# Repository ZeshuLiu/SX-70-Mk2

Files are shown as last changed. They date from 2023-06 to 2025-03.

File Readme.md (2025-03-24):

# SX-70 Mk2

## 介绍
针对SX-70 Sonnar相机的现代化改造，在保留原本机身的自动功能的情况下，提供更直接的手动控制方式，能够更加自由地进行拍摄。**安装机身控制器后手动控制更加方便** \
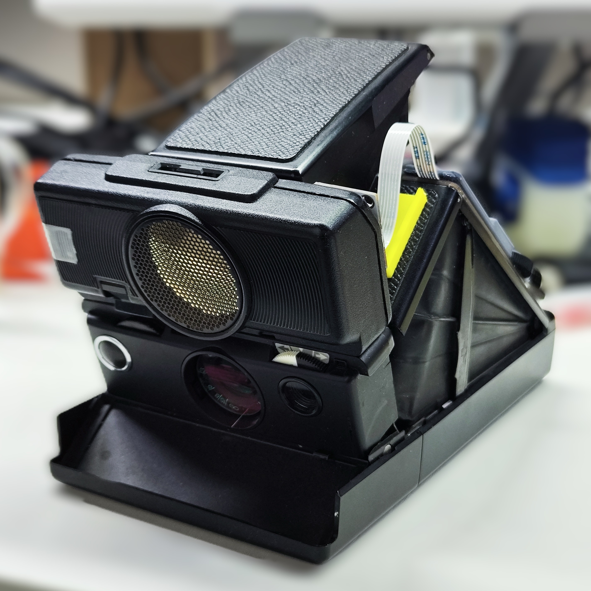
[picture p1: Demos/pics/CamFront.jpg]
相机正面 Front


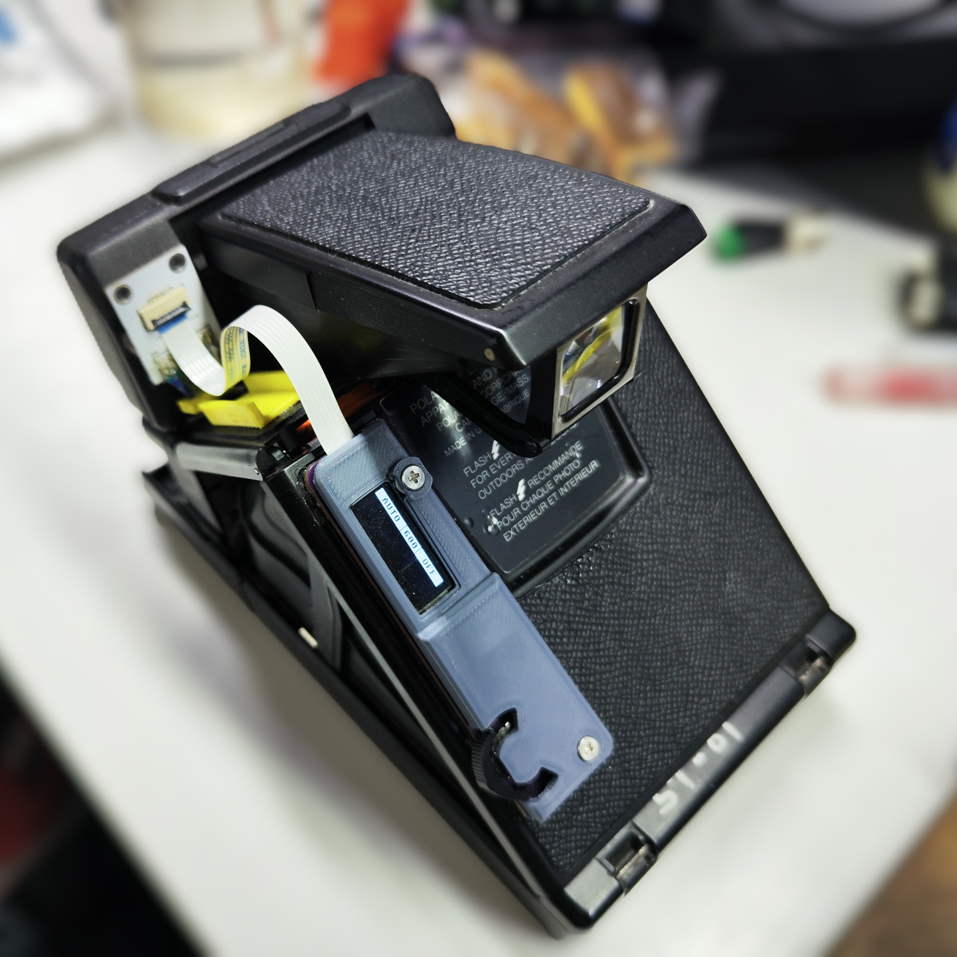
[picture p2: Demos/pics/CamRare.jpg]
相机背面 Rare


### 项目组成

项目中包含几个部分的硬件：

1. [相机主控板](https://github.com/ZeshuLiu/SX-70-Mk2/tree/main/Hardwares/MainController)：替换相机机头内原装的控制器，接管相机的控制。
2. [机身控制器](https://github.com/ZeshuLiu/SX-70-Mk2/tree/main/Hardwares/Body_controller)：显示当前相机工作状态并提供用于交互的按键。粘贴在机身背部，不会增加相机高度，因此大部分相机包依旧可以通用，与相机主控板连接需要[转接器](https://github.com/ZeshuLiu/SX-70-Mk2/tree/main/Fabrication/Wire2FPC)以及60mm长1.0mm间距的6pin Fpc排线。
3. [闪光灯接口](https://github.com/ZeshuLiu/SX-70-Mk2/tree/main/Hardwares/Flash_Plug)：**(还未实际测试)**，从原本的闪光灯排上引出3.5mm接口，用于外置闪光灯。
4. [机身电池](https://github.com/ZeshuLiu/SX-70-Mk2/tree/main/Hardwares/PowerBack)：**(正在开发中)**，通过相机底部的两个触点为相机供电，可以使用iType相纸进行拍摄。

### 开发

PCB部分除闪光灯接口使用嘉立创EDA外均使用KiCad8绘制，仓库提供了相应的工程和光绘(gerber)文件。

Rev1.x - Rev2.x 版本的主控使用RP2040，通过micropython编程。micropython中硬件定时器最小单位为1ms，后续考虑换用C语言获得更高定时器配置精度。

## 性能参数
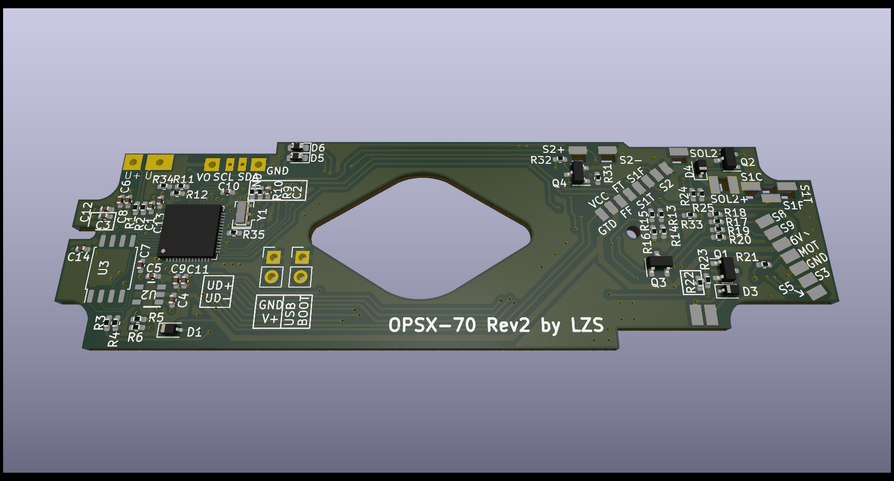
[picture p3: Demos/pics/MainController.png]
相机主控

相机主控可以单独使用，此时可以进行自动测光和曝光，如果需要使用B、T以及手动模式需要配备机身控制器。

**快门速度：** 1/2000s-1s，支持B门及T门 \
**自拍定时：** 3s 5s 10s （可以与T门或B门同时使用减轻机器振动的影响）\
**测光：** 目前软件仅支持600型相纸，自动测光下最低快门速度1/2s  \
**闪光同步：** 插入闪光灯后快门组速度自动变为1/30s，在手动模式下可以设置慢于1/30s的快门速度来进行填充闪光。快门速度设置为快于1/30s时将会自动调整至1/30s，机身控制器上将会显示实际使用的快门速度\

*SX70的光圈在使用闪光灯时将会根据对焦距离进行收缩，此时调整黑白轮可以控制其光圈大小。本项目依旧保留了该特点，因此在使用闪光灯时请注意对焦距离以及黑白轮的位置*

## 样片

###### 自动测光：
自动测光拍摄

###### 手动曝光：
手动曝光

###### 闪光灯：
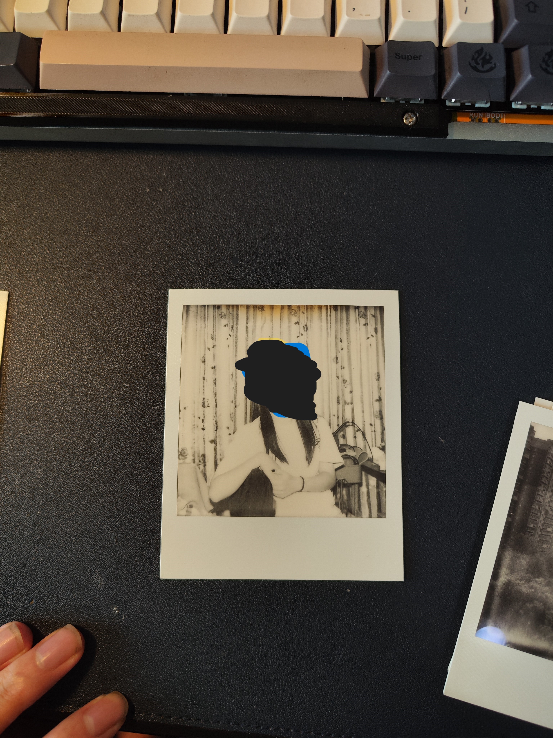
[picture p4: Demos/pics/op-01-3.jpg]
闪光灯


###### 1/1000s 快门速度：
1/1000s

## 硬件制造
光绘（Gerber）文件可以在[Fabrication](https://github.com/ZeshuLiu/OPSX-Sonnar/tree/main/Fabrication)文件夹中找到，必须使用0.8mm以下的PCB制造。需要使用 60mm 长 1mm间距的 6pin fpc软排线连接主板和机身控制器。

## 软件

把板子上的U+ U- GND VCC焊到usb线上，连接电脑后可以当作树莓派Pico开发板进行操作，上传代码的参见[这里（树莓派官网）](https://www.raspberrypi.com/documentation/microcontrollers/rp2040.html#raspberry-pi-pico)。 \
在将机身主控安装至机器内部之前需要将micropython固件及代码烧录至控制器中。后续可以通过机身控制器上的USB接口连接开发板并更新python代码。
将[code](https://github.com/ZeshuLiu/OPSX-Sonnar/tree/main/code)根目录中的所有python文件上传至控制器（文件夹不需要），**并且将g_main.py命名为 main.py(非常重要，只有这样才能够上电运行)** \
建议针对自己的快门适当调整代码中快门速度的值，可以使用这个[快门速度测试器](https://github.com/ZeshuLiu/ShutterSpeedCalibrator)来测试机器的快门速度，便于调整。

## 组装
> 提示：组装需要一些基本的工具：电烙铁、撬棒和镊子。 \
大多数sx70相机的螺丝都是非常特殊的1mm x 1mm 宝丽来螺丝，拆卸需要特殊的螺丝刀，可以从咸鱼买一把或者自己磨一个。 \
在操作之前推荐先浏览以下内容[Disassembly Guide](https://instantphotography.files.wordpress.com/2010/12/polaroid-sx-70-camera-repair-book.pdf) 或者 [SX70 camera 125ASA to 600ASA conversion](https://opensx70.com/tutorials/100-600-conversion/).

拆卸后对原本主板进行替换即可，如需要机身控制器则将左上角焊盘焊线引出即可通过转接板连接机身控制器。焊接FPC时建议使用含铅(低温)焊锡，否则有损伤机器FPC的风险。只需要将原本的拆掉并且替换上去即可，对于有焊接及机身拆装经验的人来说难度不高。

### 相关开源软件

1. 项目受到了[OPSX ](https://github.com/sunyitong/OPSX)和[openSX70](https://github.com/openSX70)的启发。
2. Rev1.x - Rev2.x 版本的128x32OLED屏幕代码：[micropython-adafruit-ssd1306 ](https://github.com/adafruit/micropython-adafruit-ssd1306)
3. 机身控制器按键使用的PCF8575：[micropython-pcf8575 ](https://github.com/mcauser/micropython-pcf8575)
4. Rev1.x-Rev2.x 主控使用的tsl2561光线传感器：[micropython-adafruit-tsl256](https://github.com/adafruit/micropython-adafruit-tsl2561)

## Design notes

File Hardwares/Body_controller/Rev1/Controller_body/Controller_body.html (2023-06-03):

# F:\Data\开发\OPSX\Sonnar\Body_controller\Rev1\Controller_body\Controller_body.kicad_sch

2023/5/12 22:40:03

Eeschema 7.0.1

Component Count:23

Ref | Qnty | Value | Part | Footprint | Description | Vendor | DNP
Bolt1, Bolt2, Bolt3 | 3 | ~ | 0JIMMY:M3_Bolt | 0JIMMY:M3_Bolt
J1 | 1 | Conn_01x06_Socket | Connector:Conn_01x06_Socket | Connector_FFC-FPC:TE_84953-6_1x06-1MP_P1.0mm_Horizontal | Generic connector, single row, 01x06, script generated
J2 | 1 | Conn_01x03_Socket | Connector:Conn_01x03_Socket | Connector_PinHeader_2.54mm:PinHeader_1x03_P2.54mm_Horizontal | Generic connector, single row, 01x03, script generated
R1, R2, R3, R4, R7, R8, R9, R10, R11, R12, R13 | 11 | 100k | Device:R | Resistor_SMD:R_0805_2012Metric_Pad1.20x1.40mm_HandSolder | Resistor
R5, R6 | 2 | 10k | Device:R | Resistor_SMD:R_0805_2012Metric_Pad1.20x1.40mm_HandSolder | Resistor
SW1 | 1 | ~ | CODED_SW:GSMR16 | SW_CODED:GSMR_16
SW2 | 1 | ~ | CODED_SW:GSMR10S | SW_CODED:GSMR_10S
SW3 | 1 | ~ | CODED_SW:3Direction_5Pin | SW_CODED:Direction3 Pin5
U1 | 1 | PCF8575PWR | PCF8575PWR:PCF8575PWR | SOP65P640X120-24N
U2 | 1 | ~ | 0JIMMY:OLED_0.96''_i2c | 0JIMMY:OLED 0.96 i2c

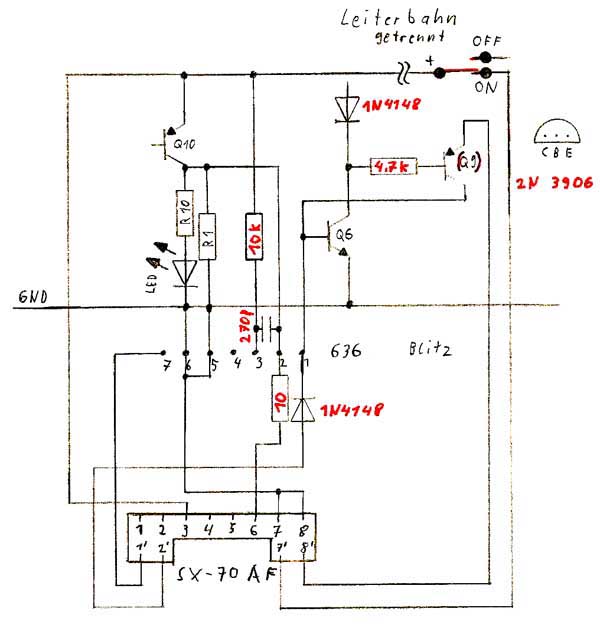
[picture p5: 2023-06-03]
Hardwares/Flash_Plug/Flash-schaltplan2.jpg

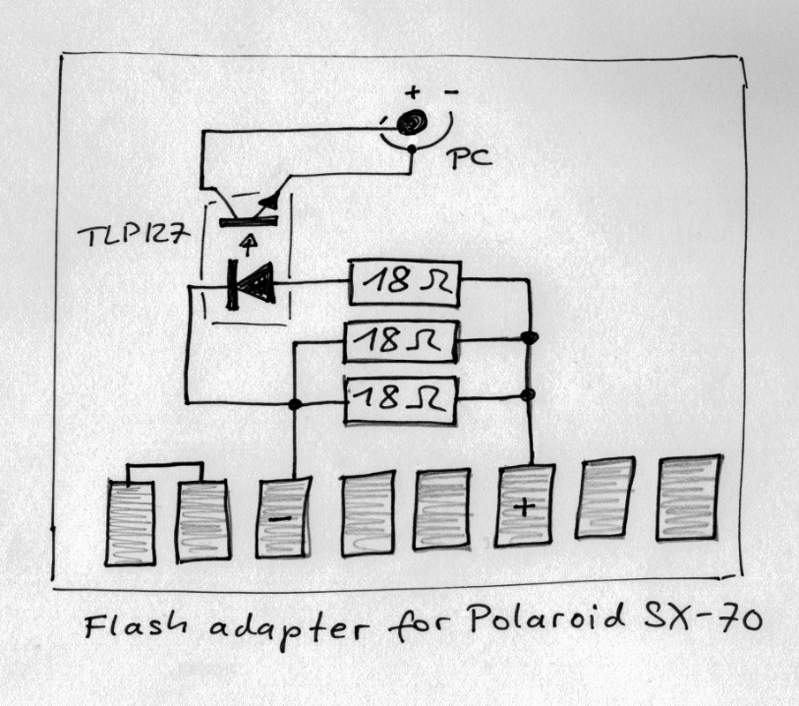
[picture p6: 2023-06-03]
Hardwares/Flash_Plug/adaptercircuit2.jpg

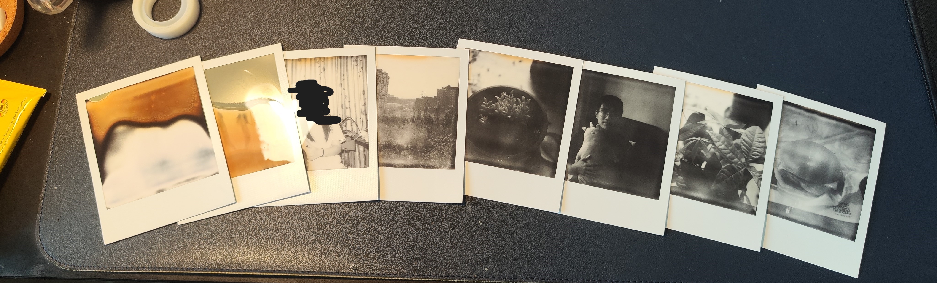
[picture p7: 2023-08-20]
Demos/pics/op-01-all.jpg

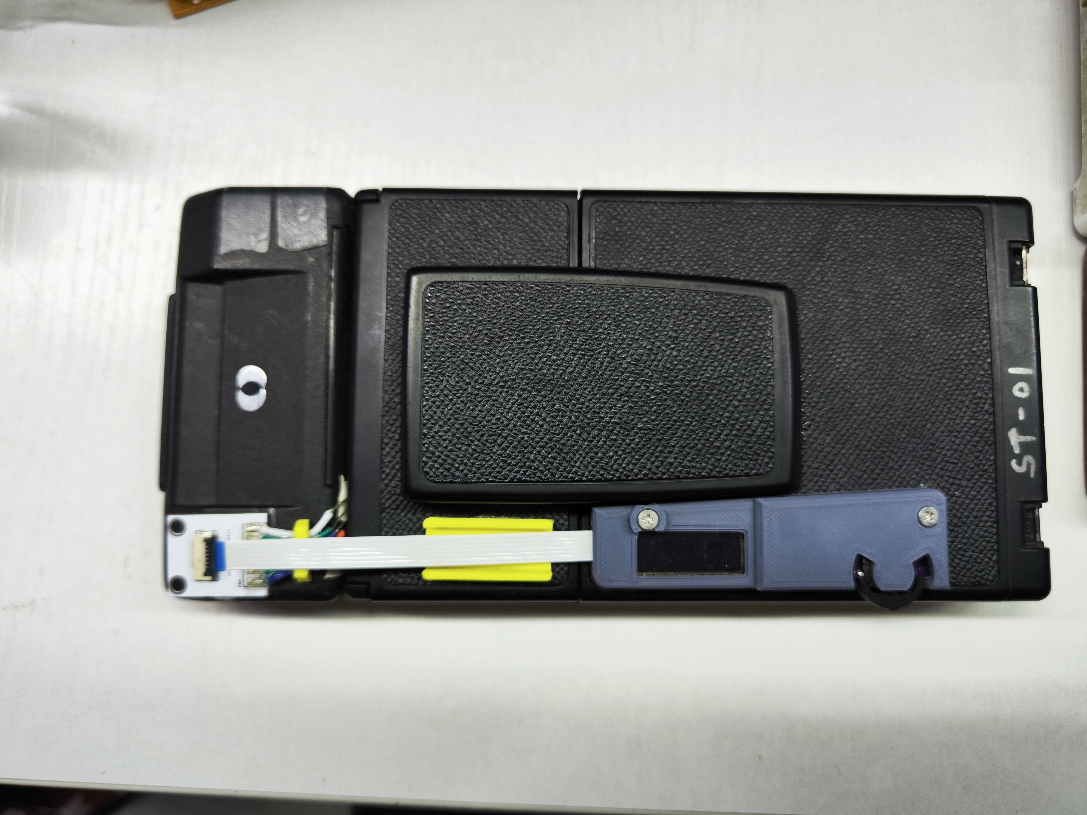
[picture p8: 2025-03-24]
Demos/pics/CamUP.jpg

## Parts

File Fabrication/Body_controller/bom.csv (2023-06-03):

Designator | Footprint | Quantity | Value | LCSC Part #
Bolt1, Bolt2, Bolt3 | M3_Bolt | 3 | ~
J1 | TE_84953-6_1x06-1MP_P1.0mm_Horizontal | 1 | Conn_01x06_Socket
J2 | PinHeader_1x03_P2.54mm_Horizontal | 1 | Conn_01x03_Socket
R1, R10, R11, R12, R13, R2, R3, R4, R7, R8, R9 | 805 | 11 | 100k
R5, R6 | 805 | 2 | 10k
SW1 | GSMR_16 | 1 | ~
SW2 | GSMR_10S | 1 | ~
SW3 | Direction3 Pin5 | 1 | ~
U1 | SOP65P640X120-24N | 1 | PCF8575PWR
U2 | OLED 0.96 i2c | 1 | ~

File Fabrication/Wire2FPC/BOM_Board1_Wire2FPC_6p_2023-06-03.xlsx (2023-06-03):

No. | Quantity | Device | Designator | Footprint | Description | Value | Manufacturer Part | Manufacturer | Supplier Part | Supplier | Name
1 | 1 | 640456-6 | CN1 | CONN-TH_6P-P2.54_640456-6 | 参考系列:-;间距:2.54mm;插针结构:1x6P;排数:1;每排PIN数:6;行距:-;安装方式:-;触头材质:铜合金; |  | 640456-6 | TE Connectivity(美国泰科) | C86506 | LCSC | 640456-6
2 | 1 | AFA01-S06FCC-00 | FPC1 | FPC-SMD_6P-P1.00_AFA01-S06 | 间距:1mm;触点数量:6;锁定特性:翻盖式;安装类型:卧贴;触点类型:下接; |  | AFA01-S06FCC-00 | JS(钜硕电子) | C262383 | LCSC | AFA01-S06FCC-00

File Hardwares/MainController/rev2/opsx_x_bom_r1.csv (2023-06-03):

ID | 指示符 | 封装 | 数量 | 名称 | 供应商和参考
1 | U4 | TMB6-1.55-3.8X2.6MM | 1 | OPTICAL-TSL2561T(6P-3.8X2.6MM)
2 | U2 | DBV0005A_N | 1 | TLV70430DBVR
3 | R35,R27,R26,R3 | R_0402_1005Metric_Pad0.72x0.64mm_HandSolder | 4 | 1k
4 | D6,D5 | D_0603_1608Metric_Pad1.05x0.95mm_HandSolder | 2 | LED
5 | R34 | R_0402_1005Metric_Pad0.72x0.64mm_HandSolder | 1 | 330
6 | Q3 | SOT-23 | 1 | Q_PMOS_GSD
7 | R33 | R_0402_1005Metric_Pad0.72x0.64mm_HandSolder | 1 | 2.7k
8 | R32 | R_0402_1005Metric_Pad0.72x0.64mm_HandSolder | 1 | 47k
9 | R31 | R_0402_1005Metric_Pad0.72x0.64mm_HandSolder | 1 | 5.6k
10 | Q4 | SOT-23 | 1 | MMBT3904
11 | Z3,Z2,Z1 | Selector_default | 3 | ~
12 | R30 | R_0402_1005Metric_Pad0.72x0.64mm_HandSolder | 1 | 150
13 | R29 | R_0402_1005Metric_Pad0.72x0.64mm_HandSolder | 1 | 180
14 | C15 | C_0402_1005Metric_Pad0.74x0.62mm_HandSolder | 1 | 13p
15 | U6,U5 | TSOT-23-5 | 2 | AD8603
16 | R28,R8,R25,R23 | R_0402_1005Metric_Pad0.72x0.64mm_HandSolder | 4 | 100k
17 | R7 | R_0805_2012Metric_Pad1.20x1.40mm_HandSolder | 1 | 22k
18 | R10,R16,R14,R18,R5,R20 | R_0402_1005Metric_Pad0.72x0.64mm_HandSolder | 6 | 12k
19 | C8,C14,C6,C2,C10,C12,C7,C1,C9,C11 | C_0402_1005Metric_Pad0.74x0.62mm_HandSolder | 10 | 100n
20 | R12,R15,R6,R19,R9,R17,R11,R4,R13 | R_0402_1005Metric_Pad0.72x0.64mm_HandSolder | 9 | 10k
21 | R1,R2 | R_0402_1005Metric_Pad0.72x0.64mm_HandSolder | 2 | 27.4
22 | Q2,Q1 | SOT-23 | 2 | Q_NMOS_GSD
23 | sx1 | sx70 | 1 | sx~
24 | J2,J1,J3 | PinHeader_1x02_P2.54mm_Vertical | 3 | Conn_01x02
25 | C4 | C_0402_1005Metric_Pad0.74x0.62mm_HandSolder | 1 | 0.1u
26 | Y1 | Resonator_SMD_Murata_CSTxExxV-3Pin_3.0x1.1mm | 1 | Crystal_GND2
27 | D4,D3,D1 | D_SOD-323 | 3 | 1N4148WS
28 | R24,R21,R22 | R_0402_1005Metric_Pad0.72x0.64mm_HandSolder | 3 | 100
29 | U3 | SOIC-8_5.23x5.23mm_P1.27mm | 1 | W25Q128JVS
30 | C3,C13,C5 | C_0402_1005Metric_Pad0.74x0.62mm_HandSolder | 3 | 1u
31 | U1 | RP2040-QFN-56 | 1 | RP2040
32 | D2 | Osram_SFH2430 | 1 | SFH2430

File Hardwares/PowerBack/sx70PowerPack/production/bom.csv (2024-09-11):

Designator | Footprint | Quantity | Value | LCSC Part #
5V+1 | SolderWirePad_1x01_SMD_5x10mm | 1 | 5V+
6V+1 | SolderWirePad_1x01_SMD_1x2mm | 1 | 6V+
BAT+1 | SolderWirePad_1x01_SMD_1x2mm | 1 | BAT+
BAT-1 | SolderWirePad_1x01_SMD_1x2mm | 1 | BAT-
Bolt1, Bolt2 | MountingHole_3.2mm_M3_Pad | 2 | M3_BOLT
C1 | 805 | 1 | 4.7uf
C10 | 603 | 1 | 100nf
C11 | 603 | 1 | 1nf
C12, C8 | CP_EIA-3216-18_Kemet-A | 2 | 10uf
C13 | 805 | 1 | 10uf
C2 | 805 | 1 | 10u
C7 | 805 | 1 | 1u
C9 | 603 | 1 | 1uf
CHG1, D2, D3, D4, D5, STB1 | 805 | 6 | LED
D6 | D_SMA | 1 | B340A
GND1 | SolderWirePad_1x01_SMD_5x10mm | 1 | GND
GND2 | SolderWirePad_1x01_SMD_1x2mm | 1 | GND
Hole1 | Tripod_hole | 1 | Tripod_hole
J1 | USB_C_Receptacle_GCT_USB4125-xx-x-0190_6P_TopMnt_Horizontal | 1 | USB_C_Receptacle_PowerOnly_6P
L2 | L_Cenker_CKCS6020 | 1 | 3.3uH
R1, R9 | 603 | 2 | 1k
R2, R3, R4, R5 | 603 | 4 | 3.3k
R6 | 603 | 1 | 8.2k
R7 | 603 | 1 | 69.8k
R8 | 603 | 1 | 18k
R_PRG1 | 603 | 1 | 10k
S1 | SW_SS12D07VG4 | 1 | SS12D07VG4
Sx70_Pogopin1 | sx_70_pogopin | 1 | Sx70_Pogopin
U1 | SOT-23-6 | 1 | TP4057
U3 | SOT-23-6_Handsoldering | 1 | LN60A
U4 | VSSOP-8_3.0x3.0mm_P0.65mm | 1 | TPS61085DGK

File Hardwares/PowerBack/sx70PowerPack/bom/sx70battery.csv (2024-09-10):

'Reference' | 'Value' | 'Datasheet' | 'Footprint' | 'Qty' | 'DNP'
'5V+1' | '5V+' | '~' | 'Connector_Wire:SolderWirePad_1x01_SMD_5x10mm' | '1' | ''
'6V+1' | '6V+' | '~' | 'Connector_Wire:SolderWirePad_1x01_SMD_1x2mm' | '1' | ''
'BAT+1' | 'BAT+' | '~' | 'Connector_Wire:SolderWirePad_1x01_SMD_1x2mm' | '1' | ''
'BAT-1' | 'BAT-' | '~' | 'Connector_Wire:SolderWirePad_1x01_SMD_1x2mm' | '1' | ''
'Bolt1,Bolt2' | 'M3_BOLT' | '' | 'MountingHole:MountingHole_3.2mm_M3_Pad' | '2' | ''
'C1' | '4.7uf' | '~' | 'Capacitor_SMD:C_0805_2012Metric_Pad1.18x1.45mm_HandSolder' | '1' | ''
'C2' | '10u' | '~' | 'Capacitor_SMD:C_0805_2012Metric_Pad1.18x1.45mm_HandSolder' | '1' | ''
'C7' | '1u' | '~' | 'Capacitor_SMD:C_0805_2012Metric_Pad1.18x1.45mm_HandSolder' | '1' | ''
'C8,C12,C13' | '10uf' | '~' | '-- 混合值 --' | '3' | ''
'C9' | '1uf' | '~' | 'Capacitor_SMD:C_0603_1608Metric_Pad1.08x0.95mm_HandSolder' | '1' | ''
'C10' | '100nf' | '~' | 'Capacitor_SMD:C_0603_1608Metric_Pad1.08x0.95mm_HandSolder' | '1' | ''
'C11' | '1nf' | '~' | 'Capacitor_SMD:C_0603_1608Metric_Pad1.08x0.95mm_HandSolder' | '1' | ''
'CHG1,D2,D3,D4,D5,STB1' | 'LED' | '~' | 'LED_SMD:LED_0805_2012Metric_Pad1.15x1.40mm_HandSolder' | '6' | ''
'D6' | 'B340A' | '~' | 'Diode_SMD:D_SMA' | '1' | ''
'GND1,GND2' | 'GND' | '~' | '-- 混合值 --' | '2' | ''
'Hole1' | 'Tripod_hole' | '' | 'Jimmy_Library:Tripod_hole' | '1' | ''
'J1' | 'USB_C_Receptacle_PowerOnly_6P' | 'https://www.usb.org/sites/default/files/documents/usb_type-c.zip' | 'Connector_USB:USB_C_Receptacle_GCT_USB4125-xx-x-0190_6P_TopMnt_Horizontal' | '1' | ''
'L2' | '3.3uH' | '~' | 'Inductor_SMD:L_Cenker_CKCS6020' | '1' | ''
'R1,R9' | '1k' | '~' | 'Resistor_SMD:R_0603_1608Metric_Pad0.98x0.95mm_HandSolder' | '2' | ''
'R2,R3,R4,R5' | '3.3k' | '~' | 'Resistor_SMD:R_0603_1608Metric_Pad0.98x0.95mm_HandSolder' | '4' | ''
'R6' | '8.2k' | '~' | 'Resistor_SMD:R_0603_1608Metric_Pad0.98x0.95mm_HandSolder' | '1' | ''
'R7' | '69.8k' | '~' | 'Resistor_SMD:R_0603_1608Metric_Pad0.98x0.95mm_HandSolder' | '1' | ''
'R8' | '18k' | '~' | 'Resistor_SMD:R_0603_1608Metric_Pad0.98x0.95mm_HandSolder' | '1' | ''
'R_PRG1' | '10k' | '~' | 'Resistor_SMD:R_0603_1608Metric_Pad0.98x0.95mm_HandSolder' | '1' | ''
'S1' | 'SS12D07VG4' | '' | 'Jimmy_Library:SW_SS12D07VG4' | '1' | ''
'Sx70_Pogopin1' | 'Sx70_Pogopin' | '' | 'Jimmy_Library:sx_70_pogopin' | '1' | ''
'U1' | 'TP4057' | '' | 'Package_TO_SOT_SMD:SOT-23-6' | '1' | ''
'U3' | 'LN60A' | '' | 'Package_TO_SOT_SMD:SOT-23-6_Handsoldering' | '1' | ''
'U4' | 'TPS61085DGK' | 'https://www.ti.com/lit/ds/symlink/tps61085.pdf' | 'Package_SO:VSSOP-8_3.0x3.0mm_P0.65mm' | '1' | ''

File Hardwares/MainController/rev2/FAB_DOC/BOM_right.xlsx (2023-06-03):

Comment | Designator | Footprint | 嘉立创元件编号
100nF | C1,C2,C4,C6,C7,C8,C9,C10,C11,C12,C14 | 0402_C | C307331
1uF | C3,C5,C13 | 0402_C | C52923
1N4148WS | D1,D3,D4 | D_SOD-323 | C2128
LED | D5 | 0603_D | C72041
LED | D6 | 0603_D | C72038
Q_NMOS_GSD | Q1,Q2 | SOT-23 | C23521
Q_PMOS_GSD | Q3 | SOT-23 | C8549
MMBT3904 | Q4 | SOT-23 | C20526
27.4Ω | R1,R2 | 0402_R | C102945
1kΩ | R26,R27 | 0402_R | C11702
10kΩ | R4,R6,R9,R11,R12,R13,R15,R17,R19 | 0402_R | C25744
12kΩ | R5,R10,R14,R16,R18,R20 | 0402_R | C25752
100kΩ | R8,R28 | 0402_R | C25741
120Ω | R21,R22,R24 | 0402_R | C25079
5.6kΩ | R31 | 0402_R | C25908
47kΩ | R32 | 0402_R | C25792
2.7kΩ | R33 | 0402_R | C352444
330Ω | R34 | 0402_R | C25104
RP2040 | U1 | LQFN-56(7x7) | C2040
TLV70430DBVR | U2 | SOT-23-5 | C133625
W25Q128JVS | U3 | SOIC-8_5.23x5.23mm_P1.27mm | C97521
Crystal_GND2 | Y1 | Resonator_SMD_Murata_CSTxExxV-3Pin_3.0x1.1mm | C91581
1kΩ | R3,R35 | 0402_R | C11702
100kΩ | R23,R25 | 0402_R | C25741

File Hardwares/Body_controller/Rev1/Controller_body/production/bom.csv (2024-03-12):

Designator | Footprint | Quantity | Value | LCSC Part #
Bolt1, Bolt3 | M3_Bolt | 2 | ~
C1, C10, C11, C12, C2, C5, C6, C9 | 0603 | 8 | 1uF
C3, C8 | 0603 | 2 | 2.2uF
C4 | 0603 | 1 | 4.7uF
C7 | 0603 | 1 | 1uF(4.7uF)
Disp1 | SSD1306_0.91_i2c | 1 | ~
J1 | TE_84953-6_1x06-1MP_P1.0mm_Horizontal | 1 | Conn_01x06_Socket
J2 | PinHeader_1x03_P2.54mm_Horizontal | 1 | Conn_01x03_Socket
JP1, JP2, JP3 | SolderJumper-3_P1.3mm_Bridged12_RoundedPad1.0x1.5mm_NumberLabels | 3 | SolderJumper_3_Bridged12
R1 | 0603 | 1 | 390k
R11, R12, R13 | 0603 | 3 | 100k
R2 | 0603 | 1 | 4.7k
R5, R6 | 0805 | 2 | 10k
SW3 | Direction3 Pin5 | 1 | ~
U3 | SSOP-20_4.4x6.5mm_P0.65mm | 1 | PCF8574ATS

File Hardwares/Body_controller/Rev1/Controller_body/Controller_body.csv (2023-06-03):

# | Reference | Qty | Value | Footprint | DNP
1 | Bolt1, Bolt2, Bolt3 | 3 | ~ | 0JIMMY:M3_Bolt
2 | J1 | 1 | Conn_01x06_Socket | Connector_FFC-FPC:TE_84953-6_1x06-1MP_P1.0mm_Horizontal
3 | J2 | 1 | Conn_01x03_Socket | Connector_PinHeader_2.54mm:PinHeader_1x03_P2.54mm_Horizontal
4 | R1, R2, R3, R4, R7, R8, R9, R10, R11, R12, R13 | 11 | 100k | Resistor_SMD:R_0805_2012Metric_Pad1.20x1.40mm_HandSolder
5 | R5, R6 | 2 | 10k | Resistor_SMD:R_0805_2012Metric_Pad1.20x1.40mm_HandSolder
6 | SW1 | 1 | ~ | SW_CODED:GSMR_16
7 | SW2 | 1 | ~ | SW_CODED:GSMR_10S
8 | SW3 | 1 | ~ | SW_CODED:Direction3 Pin5
9 | U1 | 1 | PCF8575PWR | SOP65P640X120-24N
10 | U2 | 1 | ~ | 0JIMMY:OLED 0.96 i2c

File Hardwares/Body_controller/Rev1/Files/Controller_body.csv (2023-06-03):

ID | 指示符 | 封装 | 数量 | 名称 | 供应商和参考
1 | R6,R5 | R_0805_2012Metric_Pad1.20x1.40mm_HandSolder | 2 | 10k
2 | R8,R3,R12,R2,R10,R7,R13,R4,R11,R9,R1 | R_0805_2012Metric_Pad1.20x1.40mm_HandSolder | 11 | 100k
3 | Bolt2,Bolt3,Bolt1 | M3_Bolt | 3 | ~
4 | J1 | TE_84953-6_1x06-1MP_P1.0mm_Horizontal | 1 | Conn_01x06_Socket
5 | SW3 | Direction3 Pin5 | 1 | ~
6 | U2 | OLED 0.96 i2c | 1 | ~
7 | J2 | PinHeader_1x03_P2.54mm_Horizontal | 1 | Conn_01x03_Socket
8 | SW1 | GSMR_16 | 1 | ~
9 | U1 | SOP65P640X120-24N | 1 | PCF8575PWR
10 | SW2 | GSMR_10S | 1 | ~

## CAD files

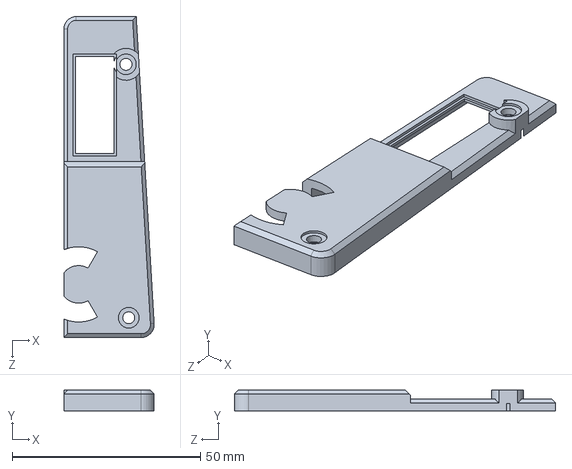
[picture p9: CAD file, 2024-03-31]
Hardwares/Body_controller/Rev1/3D_v2/ControllerCase.SLDPRT
24.0 x 5.50 x 85.2 mm

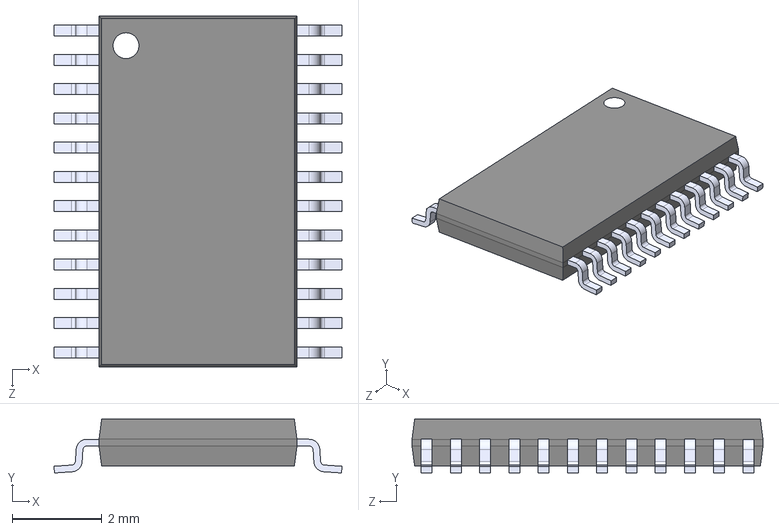
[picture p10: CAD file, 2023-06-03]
Hardwares/Body_controller/Rev1/Controller_body/PCF8575PWR/PCF8575PWR.step
6.40 x 1.20 x 7.80 mm

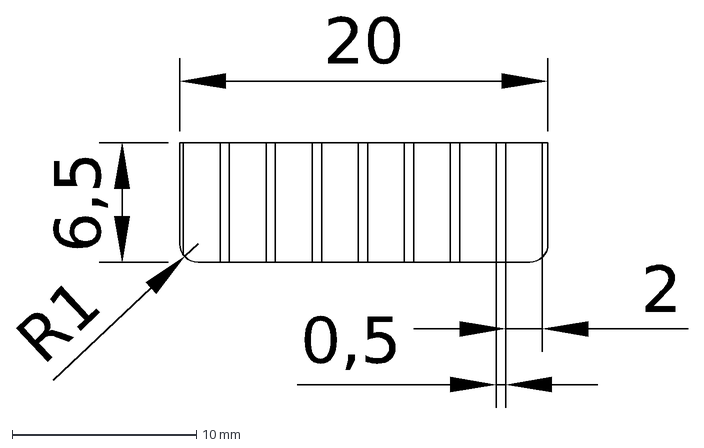
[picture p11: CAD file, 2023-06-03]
Hardwares/Flash_Plug/Flash_Plug_Size.dxf
20
6,5
R1
2
0,5

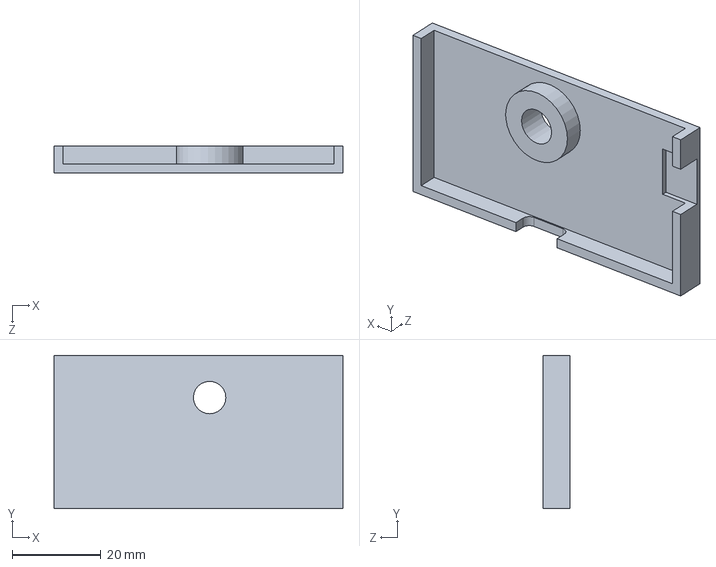
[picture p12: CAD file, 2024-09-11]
Hardwares/PowerBack/Case/Case10mmBat.SLDPRT
65.0 x 34.5 x 6.00 mm

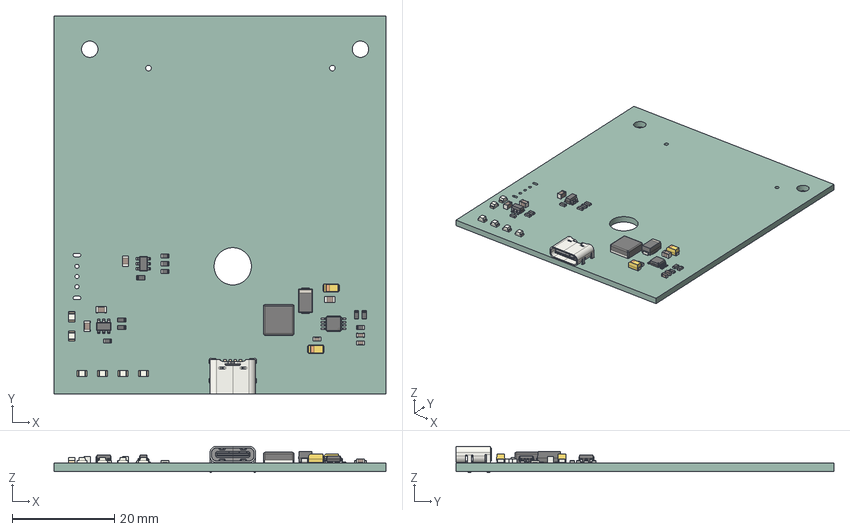
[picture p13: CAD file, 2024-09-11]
Hardwares/PowerBack/Case/PCB3D/sx70battery.step
65.0 x 74.0 x 5.16 mm
C_0805_2012Metric x 4
C_0603_1608Metric x 3
L_Cenker_CKCS6020
D_SMA
R_0603_1608Metric x 10
USB_C_Receptacle_GCT_USB4125-xx-x_6P_TopMnt_Horizontal
SOT_23_6 x 2
CP_EIA_3216_18_Kemet_A x 2
LED_0805_2012Metric x 6
VSSOP_8_30x30mm_P065mm
sx70battery_PCB

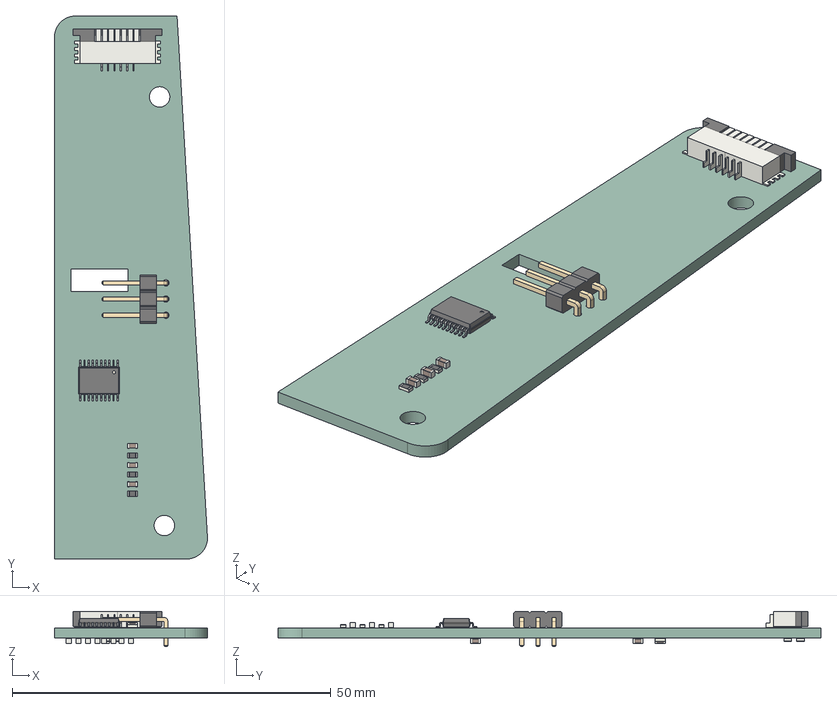
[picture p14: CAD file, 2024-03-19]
Hardwares/Body_controller/Rev1/3D_v2/Controller_body.step
24.0 x 85.2 x 5.56 mm
C_0603_1608Metric x 12
TE_84953_6
SSOP_20_44x65mm_P065mm
R_0603_1608Metric x 5
PinHeader_1x03_P254mm_Horizontal
R_0805_2012Metric x 2
Controller_body_PCB

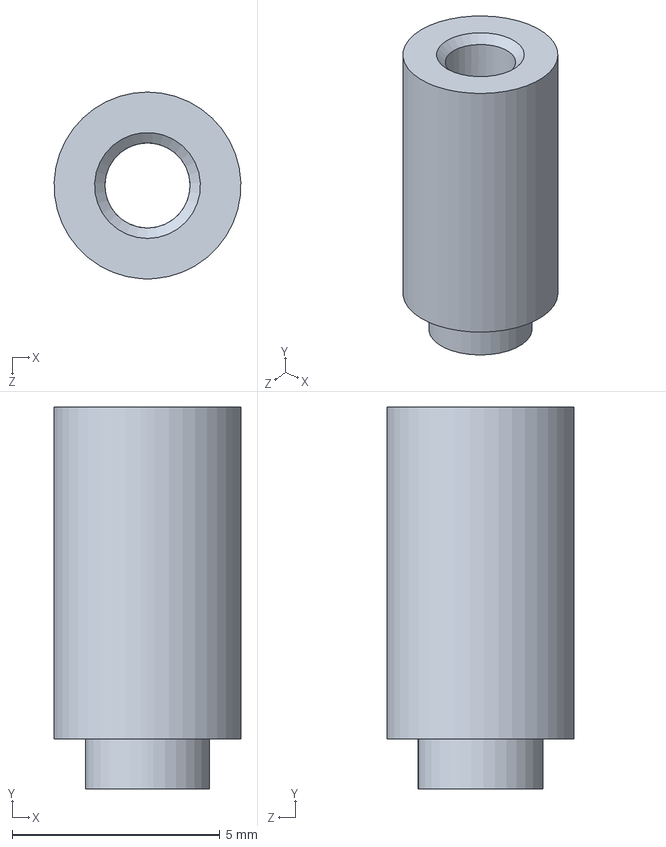
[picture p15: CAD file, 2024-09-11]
Hardwares/PowerBack/Case/贴片螺母M2.5-H8-D3.SLDPRT
4.50 x 9.20 x 4.50 mm

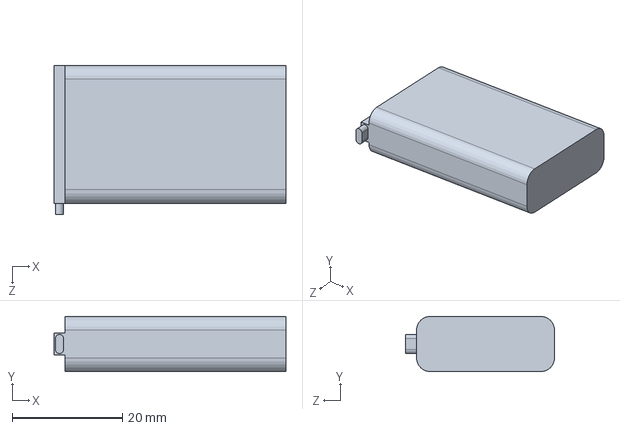
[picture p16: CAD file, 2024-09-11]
Hardwares/PowerBack/Case/102540Battery.SLDPRT
42.0 x 10.0 x 27.0 mm

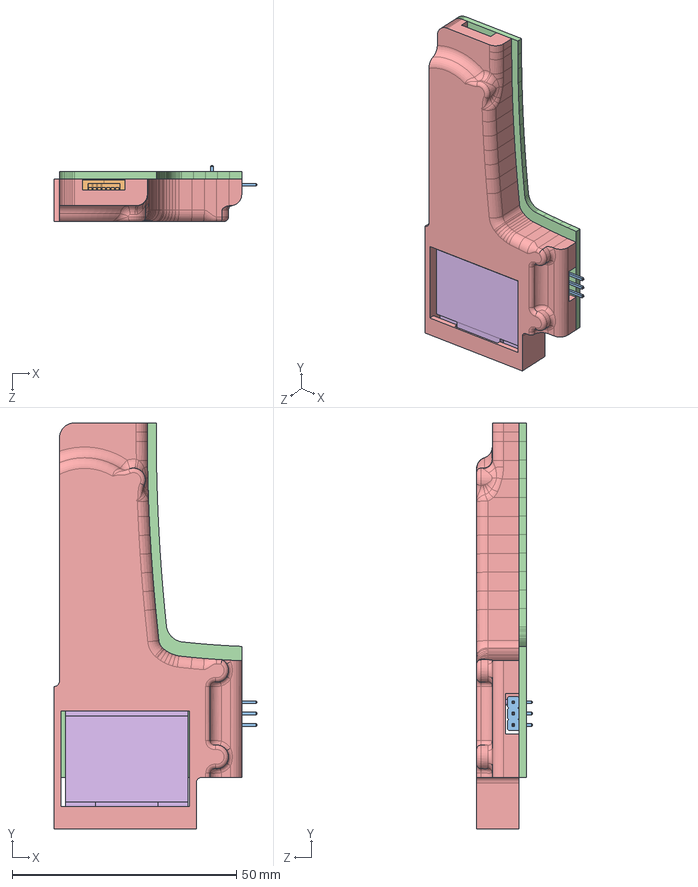
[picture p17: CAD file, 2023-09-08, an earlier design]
Hardwares/Body_controller/Rev1/3D/机身.SLDASM
45.2 x 90.5 x 12.4 mm
SOLID.step x 13
SOLID-0.step
SOLID-1.step
PCB.step
机身壳
oled

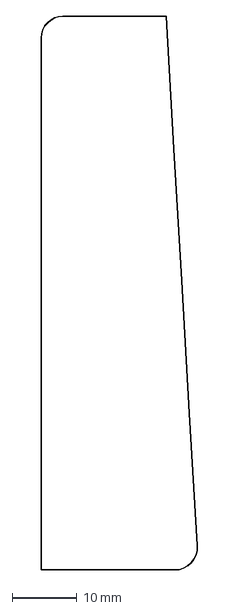
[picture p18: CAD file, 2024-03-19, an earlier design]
Hardwares/Body_controller/Rev1/3D/Controller_body.DXF
24.3 x 85.4 mm

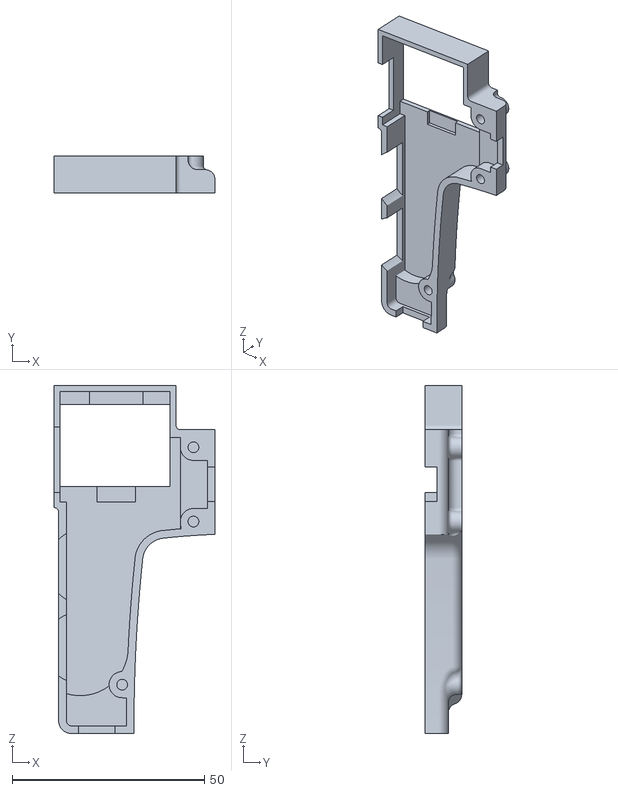
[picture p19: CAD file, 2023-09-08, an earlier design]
Hardwares/Body_controller/Rev1/3D/Case_Body_Control.STL
41.8 x 9.50 x 90.5

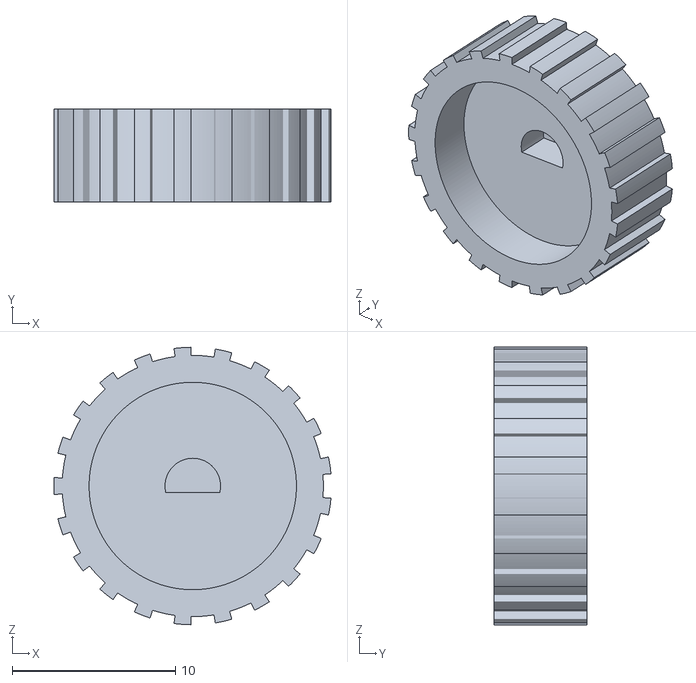
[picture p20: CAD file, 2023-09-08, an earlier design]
Hardwares/Body_controller/Rev1/3D/rot_no_val_sec_th.stl
17.0 x 5.70 x 17.0

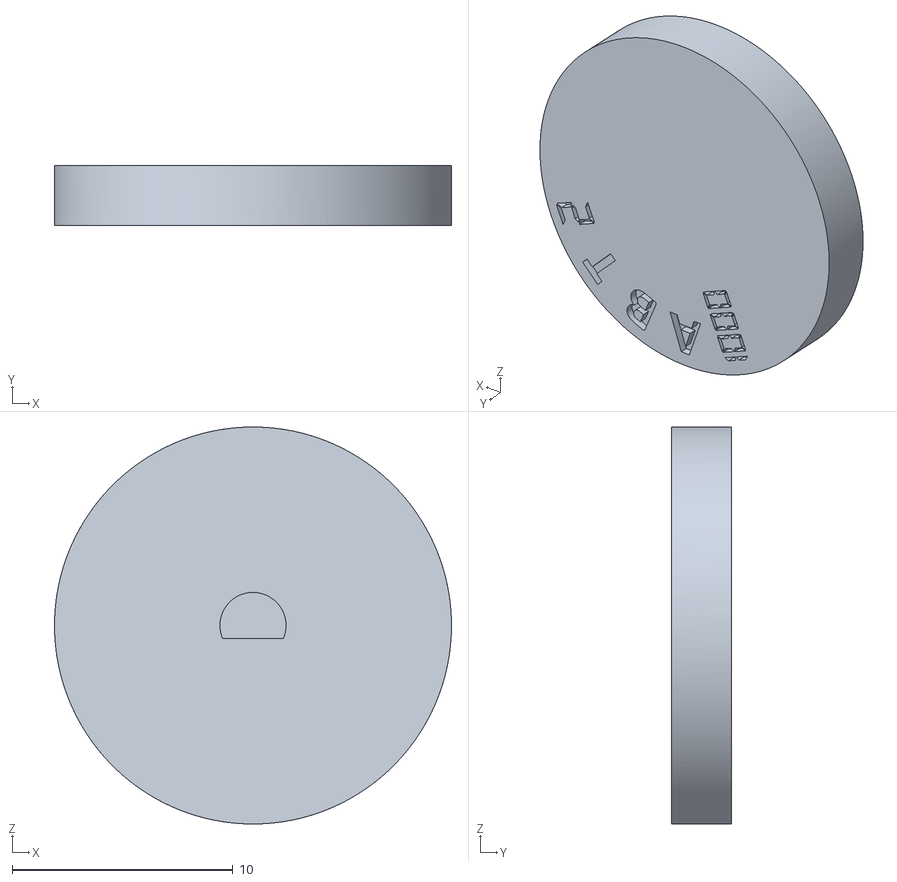
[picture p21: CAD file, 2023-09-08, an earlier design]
Hardwares/Body_controller/Rev1/3D/rot_th.stl
18.0 x 2.70 x 18.0

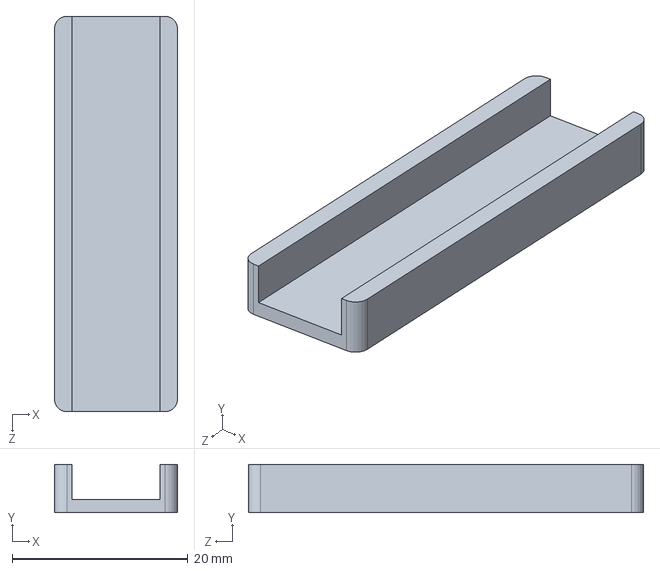
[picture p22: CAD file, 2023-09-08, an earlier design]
Hardwares/Body_controller/Rev1/3D/fpc槽.SLDPRT
14.0 x 5.50 x 45.0 mm

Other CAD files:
Hardwares/PowerBack/Case/PCB3D/ASM.SLDASM
Hardwares/Body_controller/Rev1/3D_v2/BodyControllerAsm.SLDASM
Hardwares/Body_controller/ref/sx-70-skin-template-vector-v1.10-empty.dwg
Hardwares/Body_controller/ref/sx-70-skin-sholder.dxf
Hardwares/Body_controller/Rev1/3D/OldVersions/rot_th.0006.ipt
Hardwares/Body_controller/Rev1/3D/fpc槽.STL
Hardwares/Body_controller/Rev1/3D/oled.SLDPRT
Hardwares/Body_controller/Rev1/3D/rot_no_val_sec_th.ipt
Hardwares/Body_controller/Rev1/3D/rot_no_val_th.ipt
Hardwares/Body_controller/Rev1/3D/rot_no_val_th.stl
Hardwares/Body_controller/Rev1/3D/rot_th.ipt
Hardwares/Body_controller/Rev1/3D/机身壳.SLDPRT
Hardwares/Body_controller/Rev1/3D/机身壳.STEP
Hardwares/Body_controller/Rev1/3D/机身壳.STL
Hardwares/Body_controller/Rev1/3D_v2/ControllerCase.3mf
Hardwares/Body_controller/Rev1/3D_v2/ControllerCase.STL
Hardwares/Body_controller/ref/sx-70-skin-sholder.dwg
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

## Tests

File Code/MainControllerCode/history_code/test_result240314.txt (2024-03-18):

Ver 1.1.1 20240314
时间 光强计数   打开时间计数    打开时间
1s  4844.48 19508   975
1s  4739.01 19484   974
1s  4694.82 19473   973
1s  4661.61 19480   974
1/2 2809.7  11500   575
1/2 2813.3  11519   575
1/2 2798.71 11499   574
1/2 2829.72 11520   576
1/4 1384.58 5732    286
1/4 1394.05 5745    287
1/4 1386.97 5736    286
1/8 713.214 3021    151
1/8 695.135 2990    149
1/8 690.575 3010    150
1/15    340.727 1469    73
1/15    348.225 1481    74
1/15    337.017 1471    73
1/30    176.796 808 40
1/30    176.571 807 40
1/30    171.317 786 39
1/60    93.346  453 22
1/60    83.2323 416 20
1/60    89.2633 444 22
1/60    91.4619 451 22
1/60    82.5633 413 20
1/60    93.1625 458 22
1/125   53.5799 284 14
1/125   48.2498 263 13
1/125   50.4483 274 13
1/125   47.3874 261 13
1/125   45.3167 252 12
1/250   29.7599 175 8
1/250   29.2124 171 8
1/250   25.6393 152 7
1/250   25.1202 152 7
1/250   26.8548 158 7
1/500   8.65013 58  2
1/500   8.4524  57  2

Ver 1.1.2 20240314
时间 光强计数   打开时间计数    打开时间
1s  7467.32 20569   1028
1s  7465.28 20568   1028
1/2 3754.55 10401   520
1/2 3751.17 10399   519
1/4 2010.53 5616    280
1/4 2005.29 5612    280
1/4 2011.26 5624    281
1/15    529.324 1566    78
1/15    525.467 1557    77
1/15    527.023 1565    78
1/30    257.698 825 41
1/30    256.158 820 41
1/30    250.928 810 40
1/30    257.552 825 41
1/60    144.912 517 25
1/60    148.892 528 26
1/60    150.377 530 26
1/125   86.9903 359 17
1/125   88.6605 363 18
1/125   93.6017 373 18
1/250   59.3335 268 13
1/250   59.7255 273 13
1/250   59.0075 273 13
1/500   33.0744 175 8
1/500   33.8287 175 8
1/500   35.1627 185 9
1/1000  16.4208 100 5
1/1000  14.7145 91  4
1/1000  15.6938 96  4

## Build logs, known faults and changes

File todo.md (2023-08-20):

### ~~接线器~~
1. ~~焊接~~ 2023.5.25
2.  ~~理线卡子3D~~ 2023.5.20
3. ~~打印理线卡子~~ 2023.5.2

### 代码
1. ~~填充闪光（> 1/30 的进行填充）~~ 23.5.20
2. 测光magic number 
3. ~~pcf8575控制代码~~ 23.5.30
4. 显示内容优化
5. ~~读取旋钮的值并且转换为快门速度~~ 23.5.30
6. T门改为LT门——快门速度从1s-4min
7. T门逻辑更改为使用旋钮设置（1s-4min）
8. 曝光补偿开启
9. 自拍倒计时

### 机身控制器
1. ~~焊接元件~~ 23.5.30
2. ~~波轮建模~~ 23.5.30
3. ~~波轮打印~~ 23.5.30
4. ~~升级版壳子~~ 23.6.3
5. 自拍倒计时

### 测试
1. ~~填充闪光~~ 23.5.30
2. ~~与机身控制器通讯~~ 23.5.30
3. ~~组合机身~~ 23.5.30

### 工程
1. 申请与原本工程合并

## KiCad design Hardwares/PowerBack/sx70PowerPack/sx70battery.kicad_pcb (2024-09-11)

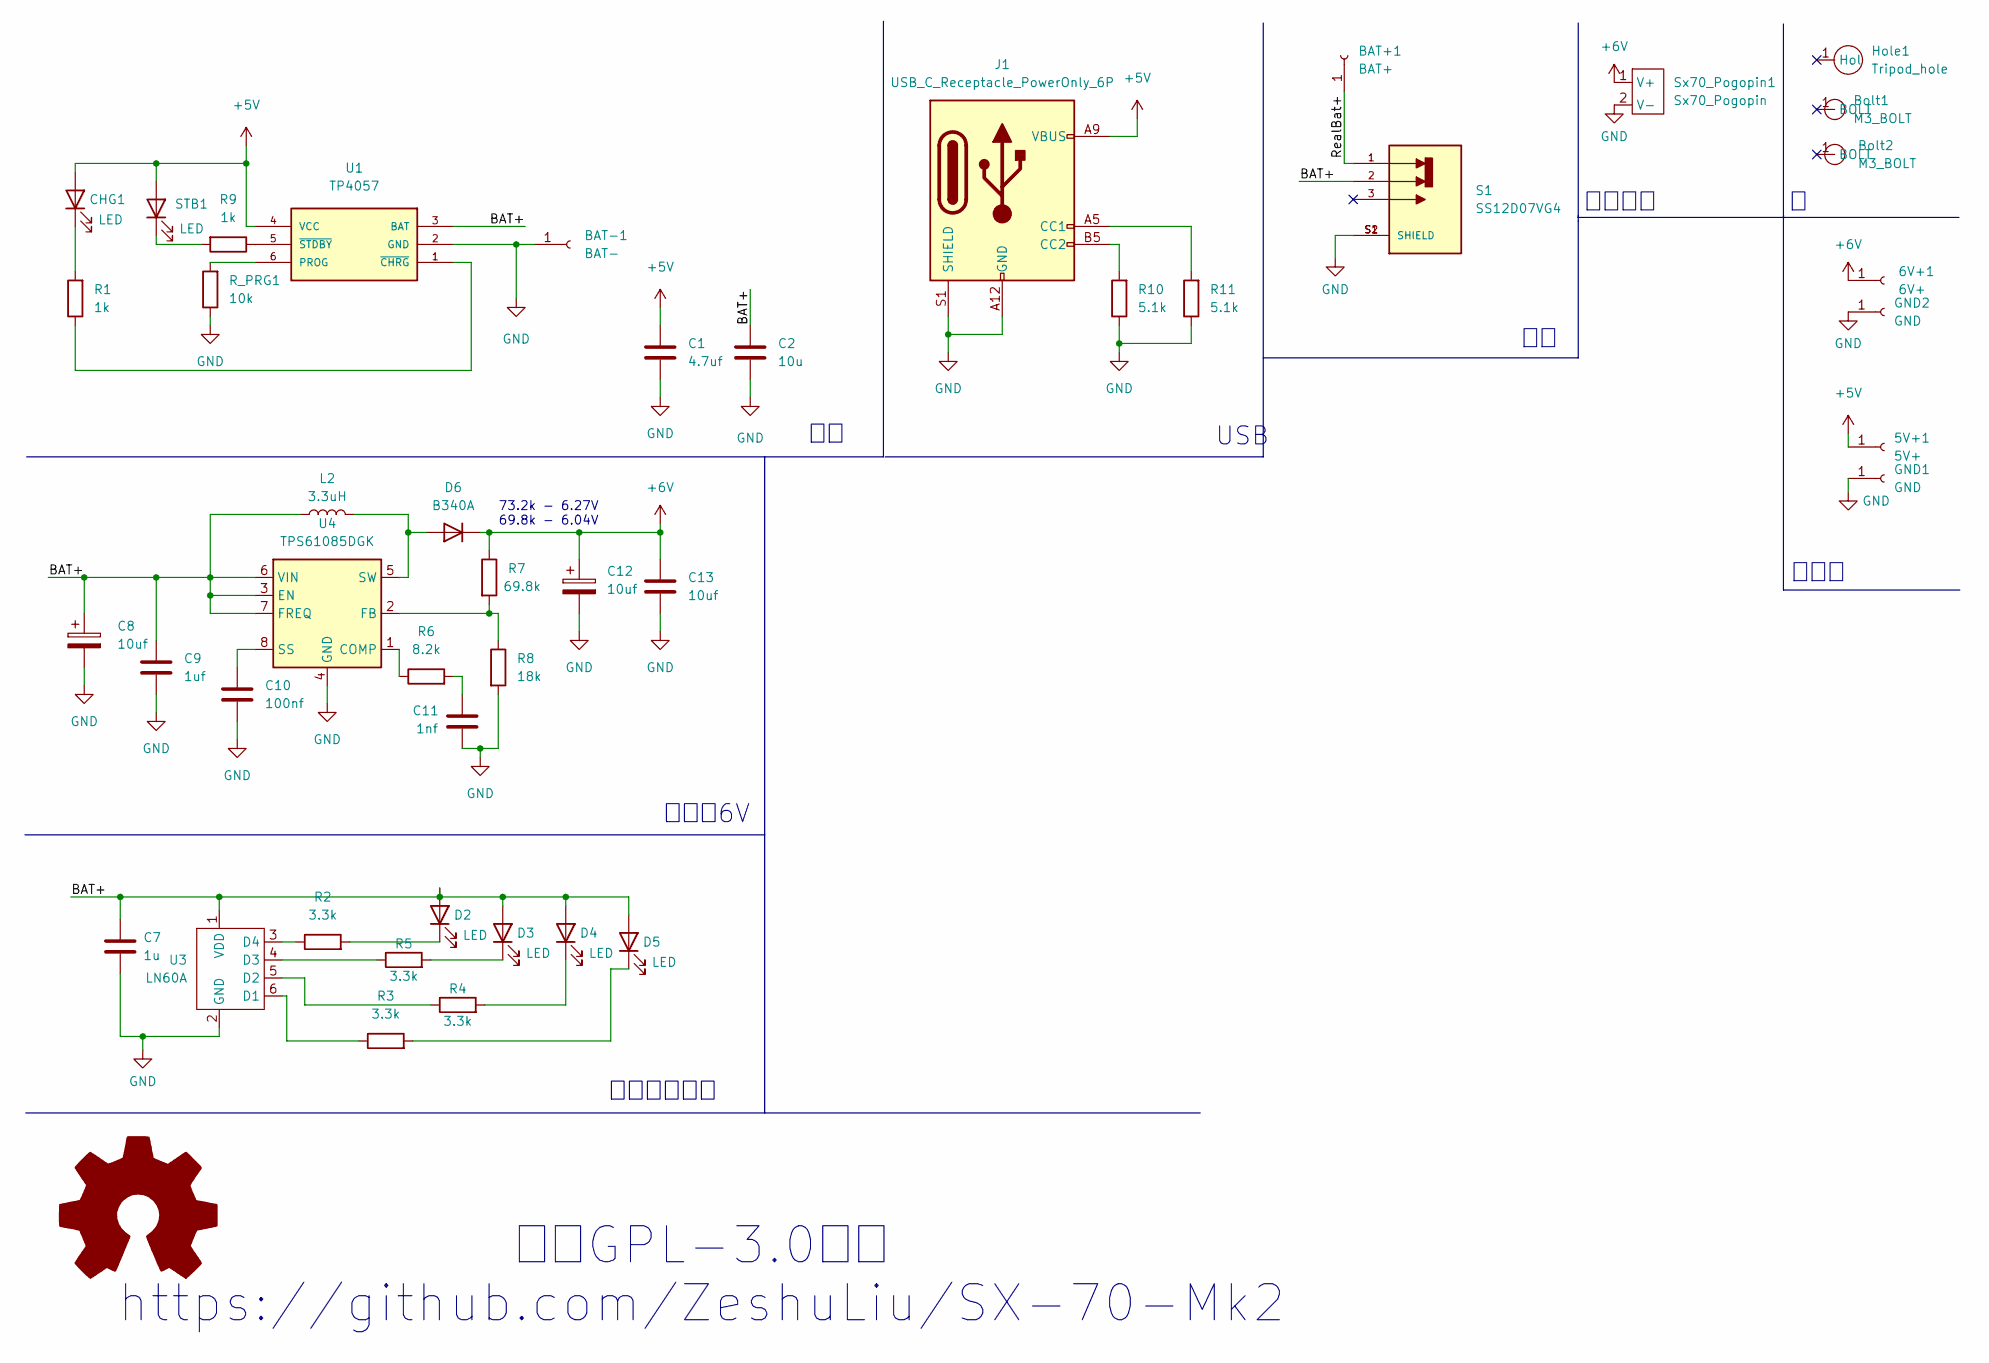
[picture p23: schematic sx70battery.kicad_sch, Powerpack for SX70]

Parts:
5V+1: 5V+; SolderWirePad_1x01_SMD_5x10mm
6V+1: 6V+; SolderWirePad_1x01_SMD_1x2mm
BAT+1: BAT+; SolderWirePad_1x01_SMD_1x2mm
BAT-1: BAT-; SolderWirePad_1x01_SMD_1x2mm
Bolt1, Bolt2: M3_BOLT; MountingHole_3.2mm_M3_Pad
C1: 4.7uf; C_0805_2012Metric_Pad1.18x1.45mm_HandSolder
C2: 10u; C_0805_2012Metric_Pad1.18x1.45mm_HandSolder
C7: 1u; C_0805_2012Metric_Pad1.18x1.45mm_HandSolder
C8, C12: 10uf; CP_EIA-3216-18_Kemet-A
C9: 1uf; C_0603_1608Metric_Pad1.08x0.95mm_HandSolder
C10: 100nf; C_0603_1608Metric_Pad1.08x0.95mm_HandSolder
C11: 1nf; C_0603_1608Metric_Pad1.08x0.95mm_HandSolder
C13: 10uf; C_0805_2012Metric_Pad1.18x1.45mm_HandSolder
CHG1: LED; LED_0805_2012Metric_Pad1.15x1.40mm_HandSolder
D2, D3, D4, D5: LED; LED_0805_2012Metric_Pad1.15x1.40mm_HandSolder
D6: B340A; D_SMA
GND1: GND; SolderWirePad_1x01_SMD_5x10mm
GND2: GND; SolderWirePad_1x01_SMD_1x2mm
Hole1: Tripod_hole
J1: USB_C_Receptacle_PowerOnly_6P; USB_C_Receptacle_GCT_USB4125-xx-x-0190_6P_TopMnt_Horizontal
L2: 3.3uH; L_Cenker_CKCS6020
R1, R9: 1k; R_0603_1608Metric_Pad0.98x0.95mm_HandSolder
R2, R3, R4, R5: 3.3k; R_0603_1608Metric_Pad0.98x0.95mm_HandSolder
R6: 8.2k; R_0603_1608Metric_Pad0.98x0.95mm_HandSolder
R7: 69.8k; R_0603_1608Metric_Pad0.98x0.95mm_HandSolder
R8: 18k; R_0603_1608Metric_Pad0.98x0.95mm_HandSolder
R10, R11: 5.1k; R_0603_1608Metric_Pad0.98x0.95mm_HandSolder
R_PRG1: 10k; R_0603_1608Metric_Pad0.98x0.95mm_HandSolder
S1: SS12D07VG4; SW_SS12D07VG4; PARTREV 1
STB1: LED; LED_0805_2012Metric_Pad1.15x1.40mm_HandSolder
Sx70_Pogopin1: Sx70_Pogopin; sx_70_pogopin
U1: TP4057; SOT-23-6
U3: LN60A; SOT-23-6_Handsoldering
U4: TPS61085DGK; VSSOP-8_3.0x3.0mm_P0.65mm

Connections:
+5V: 5V+1.1, C1.2, CHG1.2 (A), J1.A9 (VBUS), J1.B9 (VBUS), STB1.2 (A), U1.4 (VCC)
+6V: 6V+1.1, C12.1, C13.1, D6.1 (K), R7.1, Sx70_Pogopin1.1 (V+)
/BAT+: C2.1, C7.1, C8.1, C9.1, D2.2 (A), D3.2 (A), D4.2 (A), D5.2 (A), L2.1, S1.2, U1.3 (BAT), U3.1 (VDD), U4.3 (EN), U4.6 (VIN), U4.7 (FREQ)
/RealBat+: BAT+1.1, S1.1
GND: BAT-1.1, C1.1, C2.2, C7.2, C8.2, C9.2, C10.2, C11.2, C12.2, C13.2, GND1.1, GND2.1, J1.A12 (GND), J1.B12 (GND), J1.S1 (SHIELD), R8.2, R10.1, R11.1, R_PRG1.1, S1.S1 (SHIELD), S1.S2 (SHIELD), Sx70_Pogopin1.2 (V-), U1.2 (GND), U3.2 (GND), U4.4 (GND)
unnamed: C11.1, R6.2
unnamed: CHG1.1 (K), R1.2
unnamed: D2.1 (K), R2.2
unnamed: D3.1 (K), R5.2
unnamed: D4.1 (K), R4.2
unnamed: D5.1 (K), R3.2
unnamed: D6.2 (A), L2.2, U4.5 (SW)
unnamed: J1.A5 (CC1), R11.2
unnamed: J1.B5 (CC2), R10.2
unnamed: R9.2, STB1.1 (K)
unnamed: R_PRG1.2, U1.6 (PROG)
unnamed: R1.1, U1.1 (~CHRG)
unnamed: R9.1, U1.5 (~STDBY)
unnamed: R3.1, U3.6 (D1)
unnamed: R4.1, U3.5 (D2)
unnamed: R5.1, U3.4 (D3)
unnamed: R2.1, U3.3 (D4)
unnamed: R6.1, U4.1 (COMP)
unnamed: R7.2, R8.1, U4.2 (FB)
unnamed: C10.1, U4.8 (SS)

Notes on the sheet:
电池升6V
USB
电池电量检测
相机供电
使用GPL-3.0许可 https://github.com/ZeshuLiu/SX-70-Mk2
测试点
73.2k - 6.27V 69.8k - 6.04V

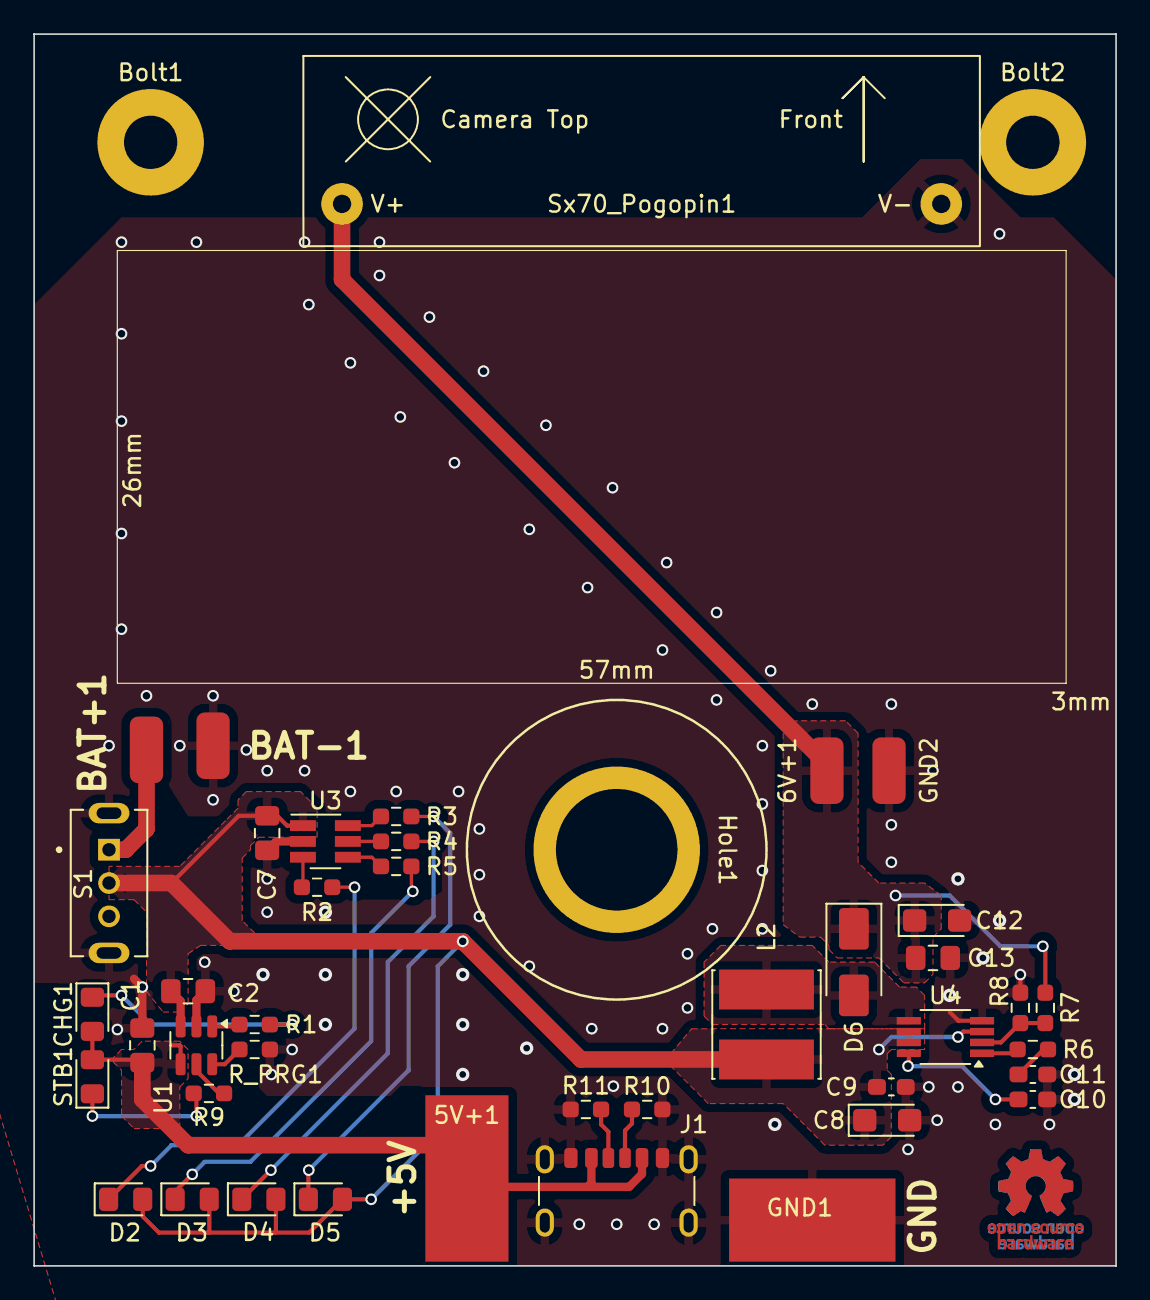
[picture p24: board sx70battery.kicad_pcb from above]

Board: 2 copper layers, 65.0 x 74.0 mm, 44 parts (0 on the bottom side), 25 nets.

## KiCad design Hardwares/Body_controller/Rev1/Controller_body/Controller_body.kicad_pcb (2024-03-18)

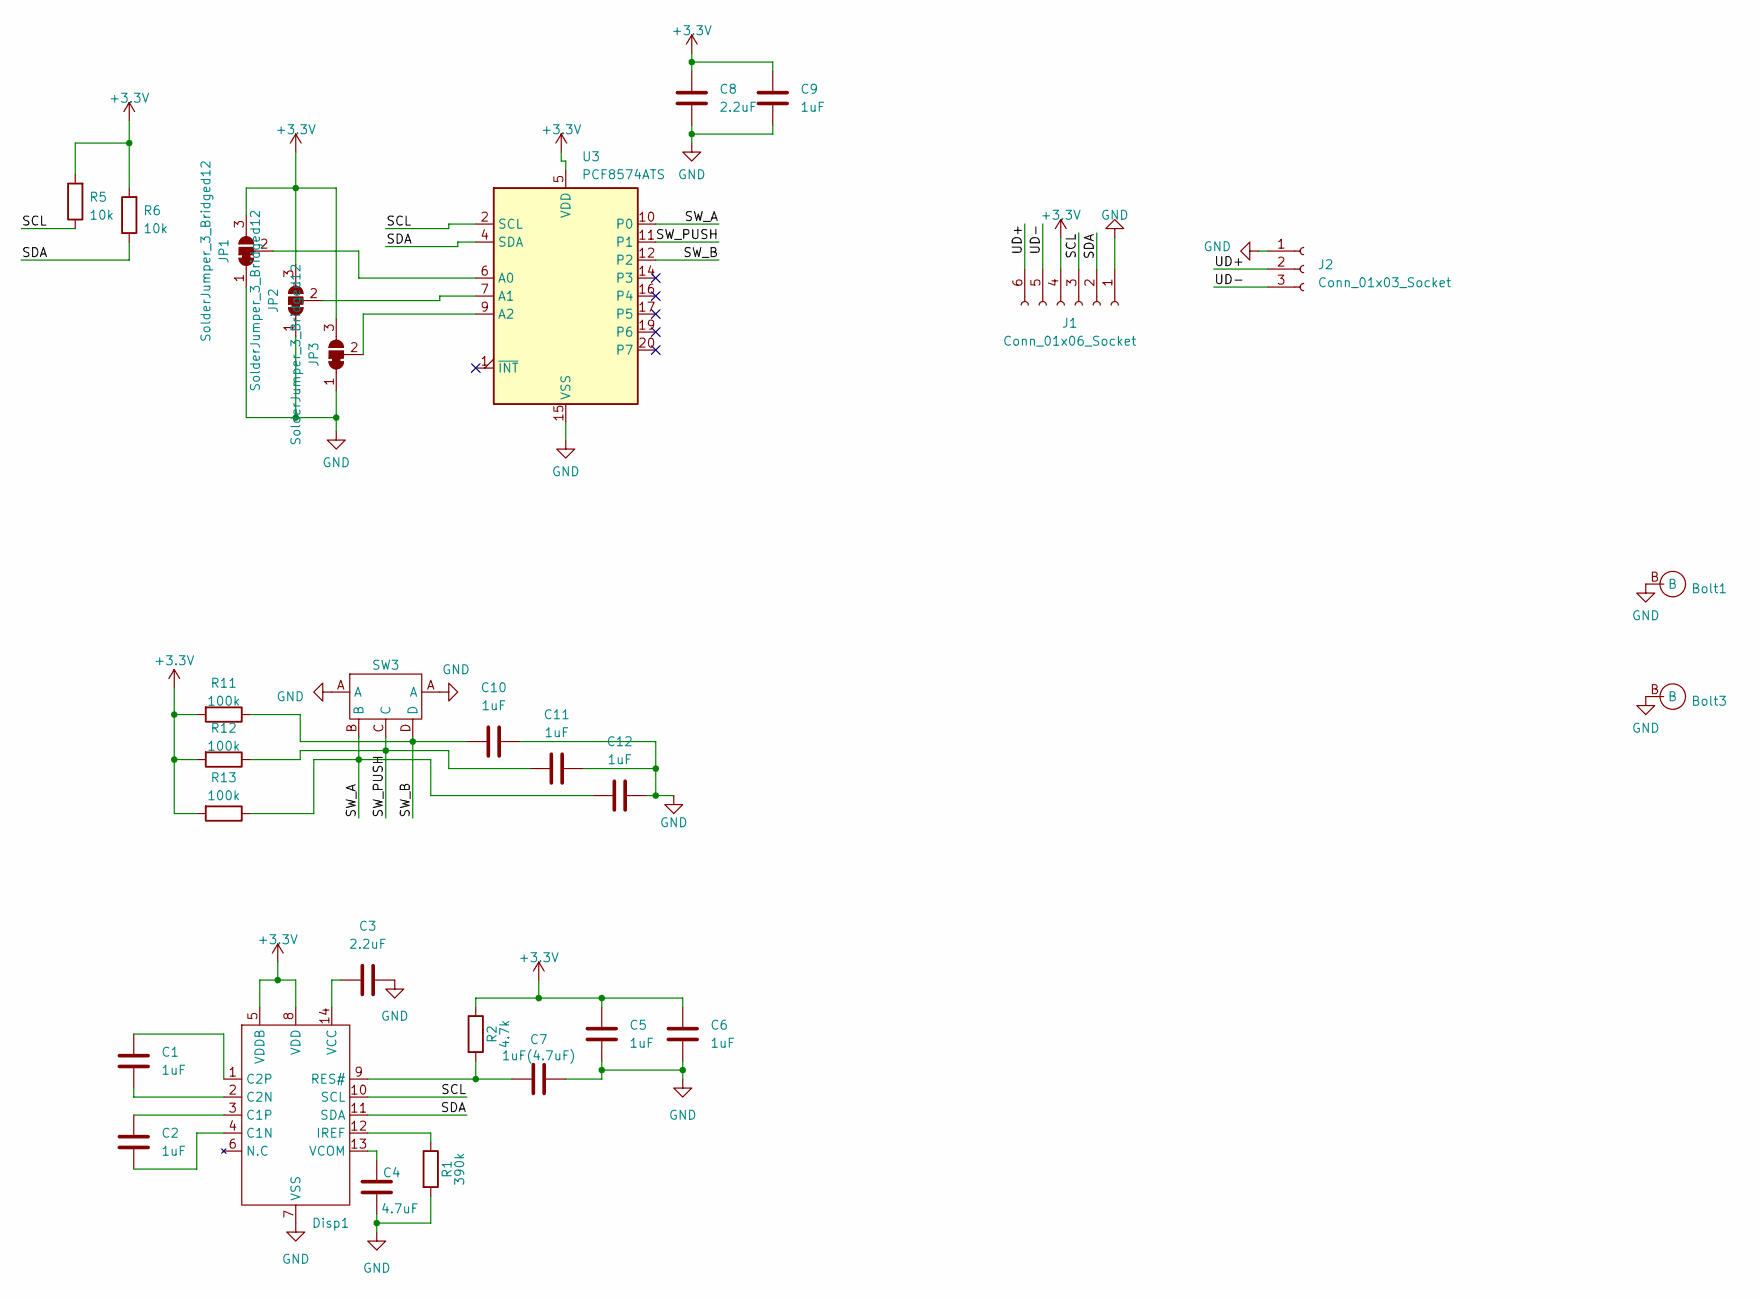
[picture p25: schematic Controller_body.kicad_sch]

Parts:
Bolt1, Bolt3: M3_Bolt
C1, C2, C5, C6, C9, C10, C11, C12: 1uF; C_0603_1608Metric_Pad1.08x0.95mm_HandSolder
C3, C8: 2.2uF; C_0603_1608Metric_Pad1.08x0.95mm_HandSolder
C4: 4.7uF; C_0603_1608Metric_Pad1.08x0.95mm_HandSolder
C7: 1uF(4.7uF); C_0603_1608Metric_Pad1.08x0.95mm_HandSolder
Disp1: SSD1306_0.91_i2c
J1: Conn_01x06_Socket; TE_84953-6_1x06-1MP_P1.0mm_Horizontal
J2: Conn_01x03_Socket; PinHeader_1x03_P2.54mm_Horizontal
JP1, JP2, JP3: SolderJumper_3_Bridged12; SolderJumper-3_P1.3mm_Bridged12_RoundedPad1.0x1.5mm_NumberL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
R1: 390k; R_0603_1608Metric_Pad0.98x0.95mm_HandSolder
R2: 4.7k; R_0603_1608Metric_Pad0.98x0.95mm_HandSolder
R5, R6: 10k; R_0805_2012Metric_Pad1.20x1.40mm_HandSolder
R11, R12, R13: 100k; R_0603_1608Metric_Pad0.98x0.95mm_HandSolder
SW3: Direction3 Pin5
U3: PCF8574ATS; SSOP-20_4.4x6.5mm_P0.65mm

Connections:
+3.3V: C5.1, C6.1, C8.1, C9.1, Disp1.5 (VDDB), Disp1.8 (VDD), J1.4, JP1.3 (B), JP2.3 (B), JP3.3 (B), R2.1, R5.2, R6.2, R11.2, R12.2, R13.2, U3.5 (VDD)
/SCL: Disp1.10 (SCL), J1.3, R5.1, U3.2 (SCL)
/SDA: Disp1.11 (SDA), J1.2, R6.1, U3.4 (SDA)
/SW_A: C12.1, R13.1, SW3.B, U3.10 (P0)
/SW_B: C10.1, R11.1, SW3.D, U3.12 (P2)
/SW_PUSH: C11.1, R12.1, SW3.C, U3.11 (P1)
/UD+: J1.6, J2.2
/UD-: J1.5, J2.3
GND: Bolt1.B, Bolt3.B, C3.2, C4.1, C5.2, C6.2, C7.2, C8.2, C9.2, C10.2, C11.2, C12.2, Disp1.7 (VSS), J1.1, J2.1, JP1.1 (A), JP2.1 (A), JP3.1 (A), R1.2, SW3.A, U3.15 (VSS)
unnamed: C2.2, Disp1.4 (C1N)
unnamed: C2.1, Disp1.3 (C1P)
unnamed: C1.2, Disp1.2 (C2N)
unnamed: C1.1, Disp1.1 (C2P)
unnamed: Disp1.12 (IREF), R1.1
unnamed: C7.1, Disp1.9 (RES#), R2.2
unnamed: C3.1, Disp1.14 (VCC)
unnamed: C4.2, Disp1.13 (VCOM)
unnamed: JP1.2 (C), U3.6 (A0)
unnamed: JP2.2 (C), U3.7 (A1)
unnamed: JP3.2 (C), U3.9 (A2)

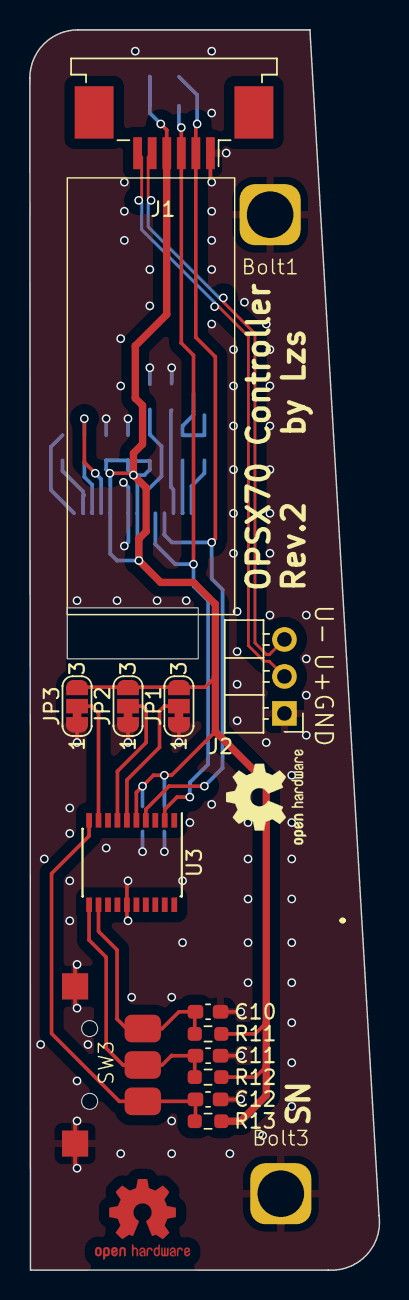
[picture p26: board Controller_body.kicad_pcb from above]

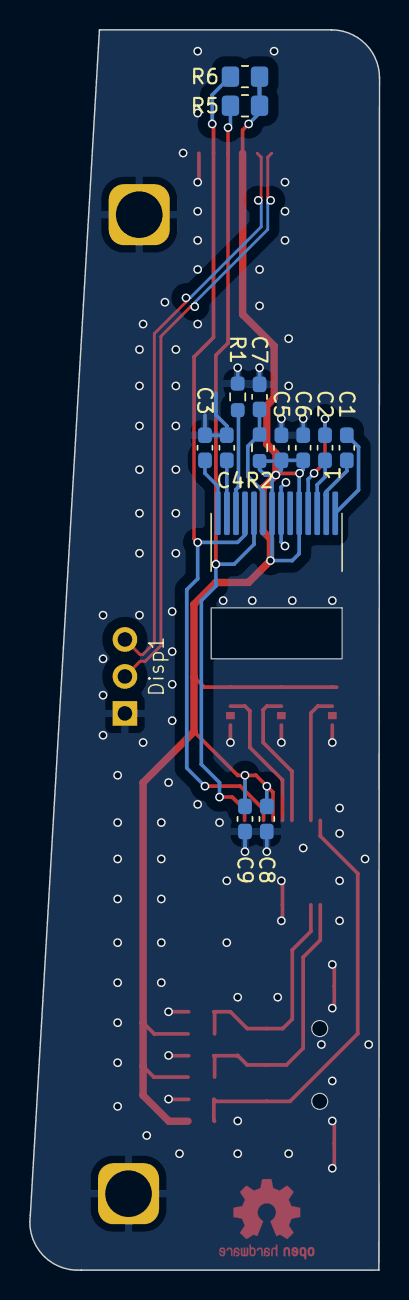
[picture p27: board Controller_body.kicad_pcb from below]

Board: 2 copper layers, 24.0 x 85.2 mm, 29 parts (14 on the bottom side), 20 nets.

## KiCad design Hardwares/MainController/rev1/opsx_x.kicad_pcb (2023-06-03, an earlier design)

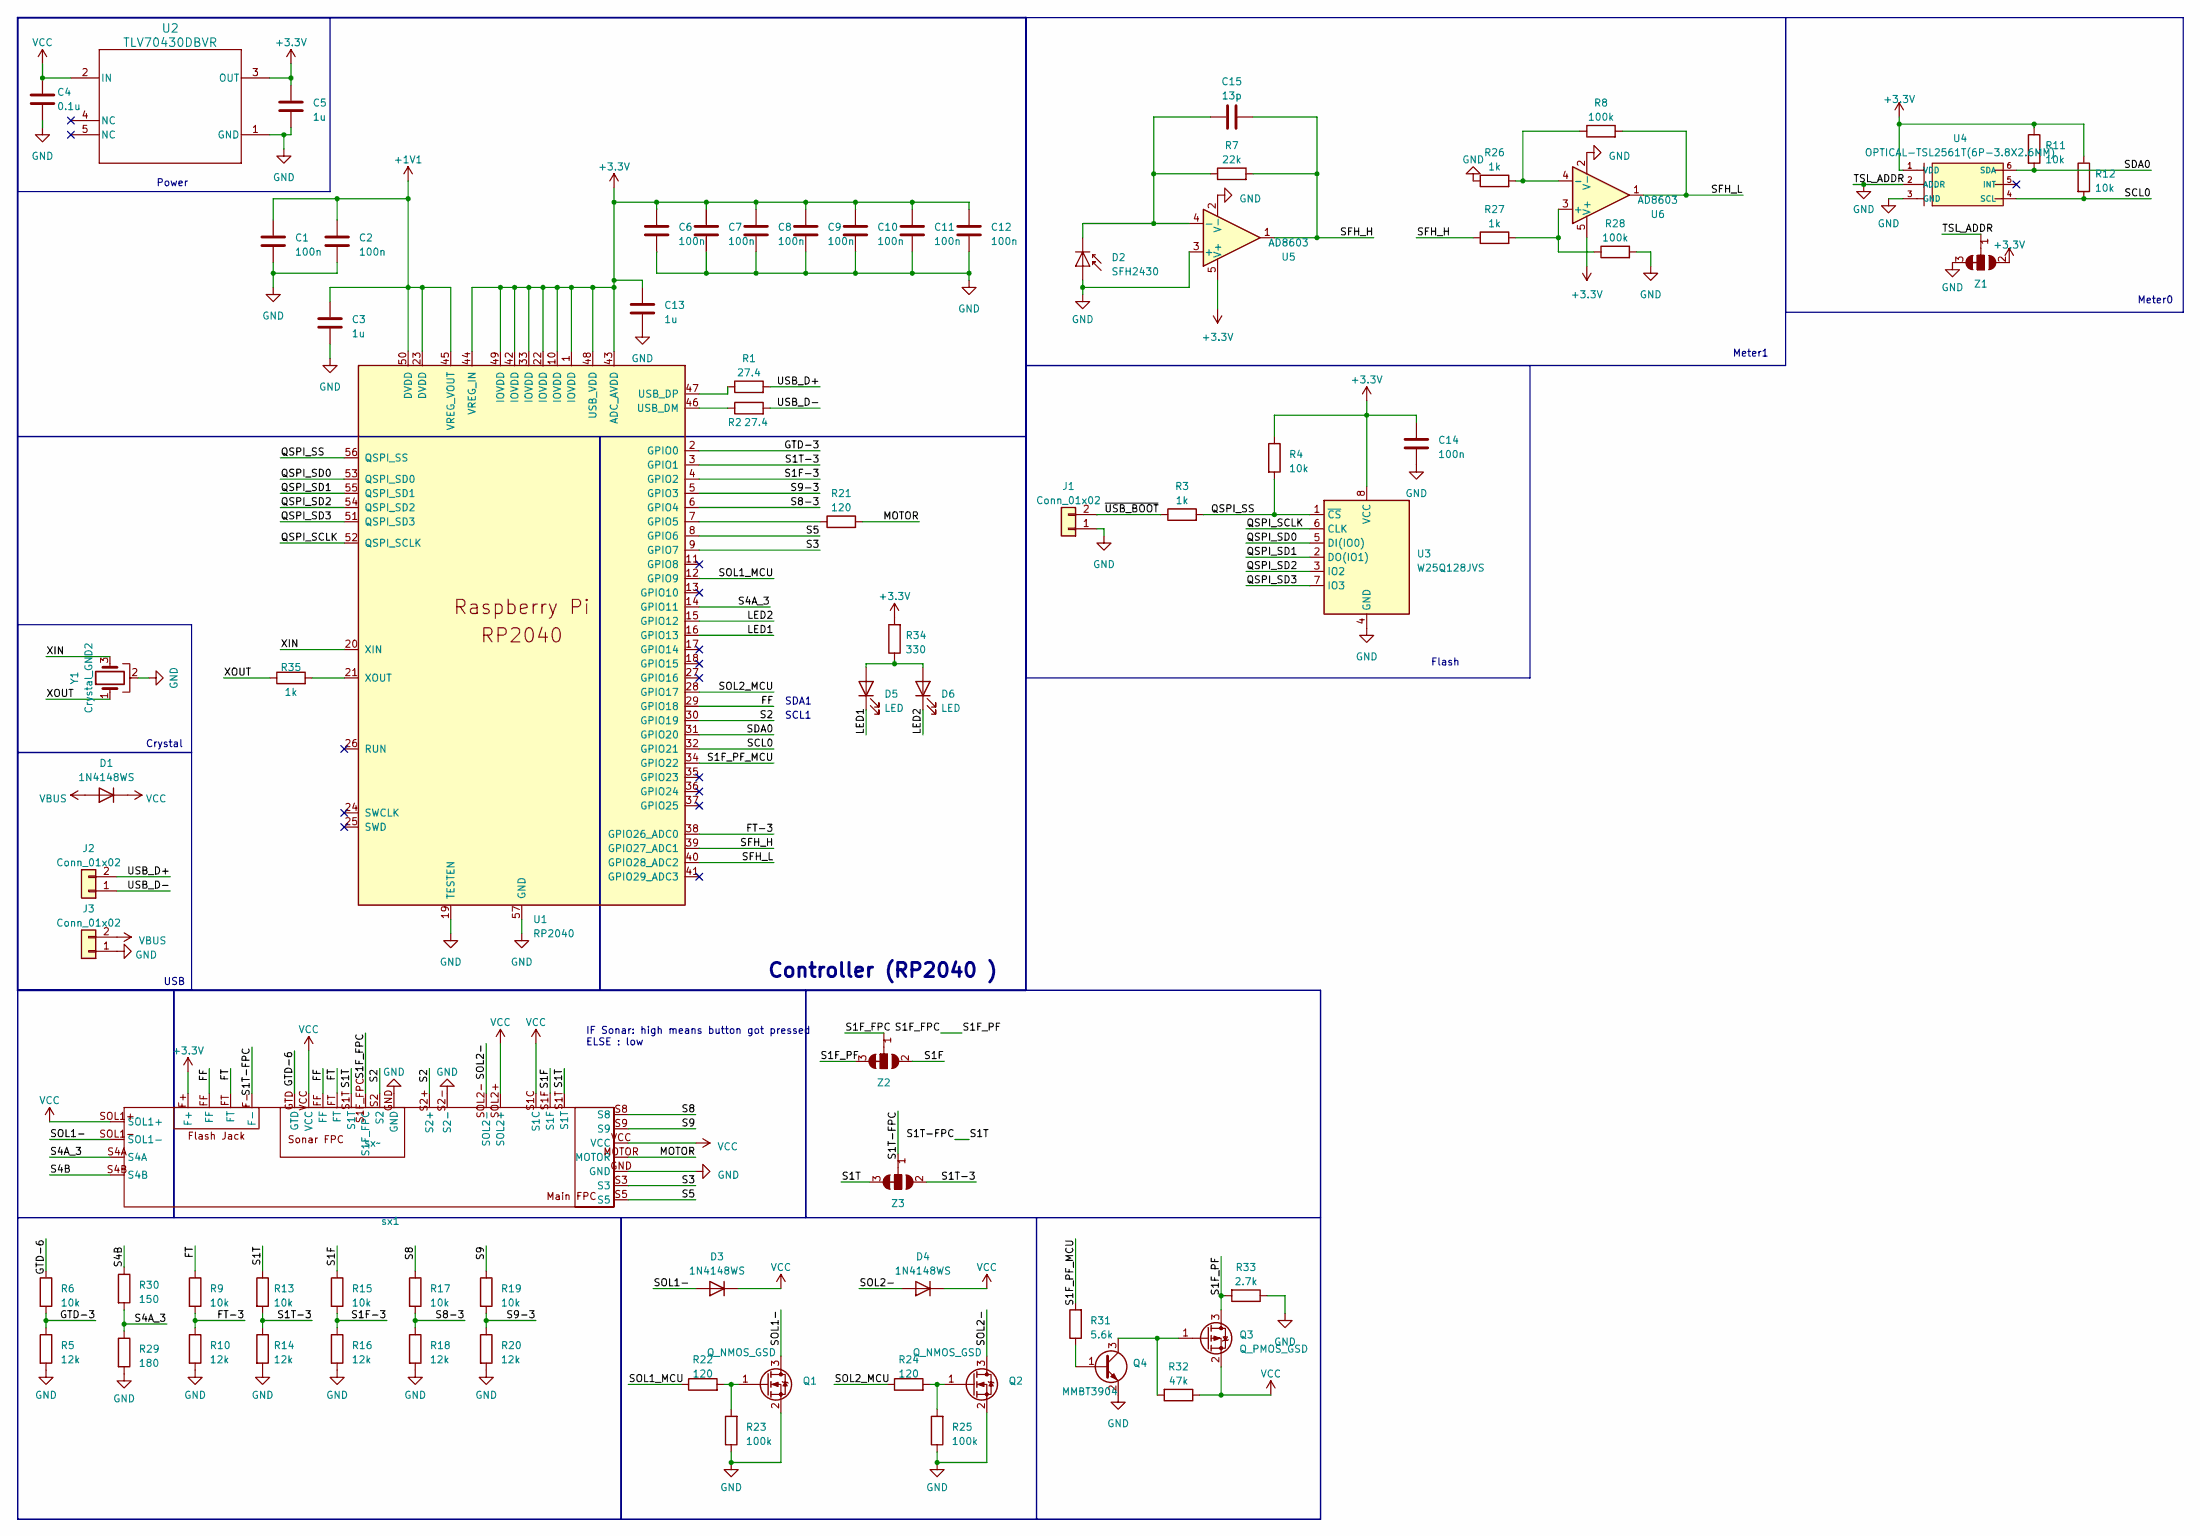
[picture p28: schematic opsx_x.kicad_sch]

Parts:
C1, C2, C6, C7, C8, C9, C10, C11, C12, C14: 100n; C_0402_1005Metric_Pad0.74x0.62mm_HandSolder
C3, C5, C13: 1u; C_0402_1005Metric_Pad0.74x0.62mm_HandSolder
C4: 0.1u; C_0402_1005Metric_Pad0.74x0.62mm_HandSolder
C15: 13p; C_0402_1005Metric_Pad0.74x0.62mm_HandSolder
D1, D3, D4: 1N4148WS; D_SOD-323
D2: SFH2430; Osram_SFH2430
D5, D6: LED; D_0603_1608Metric_Pad1.05x0.95mm_HandSolder
J1, J2, J3: Conn_01x02; PinHeader_1x02_P2.54mm_Vertical
Q1, Q2: Q_NMOS_GSD; SOT-23
Q3: Q_PMOS_GSD; SOT-23
Q4: MMBT3904; SOT-23
R1, R2: 27.4; R_0402_1005Metric_Pad0.72x0.64mm_HandSolder
R3, R26, R27, R35: 1k; R_0402_1005Metric_Pad0.72x0.64mm_HandSolder
R4, R6, R9, R11, R12, R13, R15, R17, R19: 10k; R_0402_1005Metric_Pad0.72x0.64mm_HandSolder
R5, R10, R14, R16, R18, R20: 12k; R_0402_1005Metric_Pad0.72x0.64mm_HandSolder
R7: 22k; R_0805_2012Metric_Pad1.20x1.40mm_HandSolder
R8, R23, R25, R28: 100k; R_0402_1005Metric_Pad0.72x0.64mm_HandSolder
R21, R22, R24: 120; R_0402_1005Metric_Pad0.72x0.64mm_HandSolder
R29: 180; R_0402_1005Metric_Pad0.72x0.64mm_HandSolder
R30: 150; R_0402_1005Metric_Pad0.72x0.64mm_HandSolder
R31: 5.6k; R_0402_1005Metric_Pad0.72x0.64mm_HandSolder
R32: 47k; R_0402_1005Metric_Pad0.72x0.64mm_HandSolder
R33: 2.7k; R_0402_1005Metric_Pad0.72x0.64mm_HandSolder
R34: 330; R_0402_1005Metric_Pad0.72x0.64mm_HandSolder
U1: RP2040; RP2040-QFN-56
U2: TLV70430DBVR; DBV0005A_N
U3: W25Q128JVS; SOIC-8_5.23x5.23mm_P1.27mm
U4: OPTICAL-TSL2561T(6P-3.8X2.6MM); TMB6-1.55-3.8X2.6MM; MPN TSL2561T
U5, U6: AD8603; TSOT-23-5
Y1: Crystal_GND2; Resonator_SMD_Murata_CSTxExxV-3Pin_3.0x1.1mm
Z1, Z2, Z3: Selector_default
sx1: sx~; sx70

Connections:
+1V1: C1.1, C2.1, C3.1, U1.23 (DVDD), U1.45 (VREG_VOUT), U1.50 (DVDD)
+3.3V: C5.1, C6.1, C7.1, C8.1, C9.1, C10.1, C11.1, C12.1, C13.1, C14.1, R4.1, R11.1, R12.1, R34.2, U1.1 (IOVDD), U1.10 (IOVDD), U1.22 (IOVDD), U1.33 (IOVDD), U1.42 (IOVDD), U1.43 (ADC_AVDD), U1.44 (VREG_IN), U1.48 (USB_VDD), U1.49 (IOVDD), U2.3 (OUT), U3.8 (VCC), U4.1 (VDD), U5.5 (V+), U6.5 (V+), Z1.1, sx1.F+
/FF: U1.29 (GPIO18), sx1.FF
/FT: R9.1, sx1.FT
/FT-3: R9.2, R10.1, U1.38 (GPIO26_ADC0)
/GTD-3: R5.1, R6.2, U1.2 (GPIO0)
/GTD-6: R6.1, sx1.GTD
/LED1: D5.1 (K), U1.16 (GPIO13)
/LED2: D6.1 (K), U1.15 (GPIO12)
/MOTOR: R21.2, sx1.MOTOR
/QSPI_SCLK: U1.52 (QSPI_SCLK), U3.6 (CLK)
/QSPI_SD0: U1.53 (QSPI_SD0), U3.5 (DI(IO0))
/QSPI_SD1: U1.55 (QSPI_SD1), U3.2 (DO(IO1))
/QSPI_SD2: U1.54 (QSPI_SD2), U3.3 (IO2)
/QSPI_SD3: U1.51 (QSPI_SD3), U3.7 (IO3)
/QSPI_SS: R3.2, R4.2, U1.56 (QSPI_SS), U3.1 (~CS)
/S1F: R15.1, Z2.1, sx1.S1F
/S1F-3: R15.2, R16.1, U1.4 (GPIO2)
/S1F_FPC: Q3.3 (D), R33.2, Z2.2, Z2.3, sx1.S1F_FPC
/S1F_PF_MCU: R31.2, U1.34 (GPIO22)
/S1T: R13.1, Z3.2, Z3.3, sx1.F-, sx1.S1T
/S1T-3: R13.2, R14.1, U1.3 (GPIO1), Z3.1
/S2: U1.30 (GPIO19), sx1.S2, sx1.S2+
/S3: U1.9 (GPIO7), sx1.S3
/S4A_3: R29.1, R30.2, U1.14 (GPIO11), sx1.S4A
/S4B: R30.1, sx1.S4B
/S5: U1.8 (GPIO6), sx1.S5
/S8: R17.1, sx1.S8
/S8-3: R17.2, R18.1, U1.6 (GPIO4)
/S9: R19.1, sx1.S9
/S9-3: R19.2, R20.1, U1.5 (GPIO3)
/SCL0: R12.2, U1.32 (GPIO21), U4.4 (SCL)
/SDA0: R11.2, U1.31 (GPIO20), U4.6 (SDA)
/SFH_H: C15.2, R7.2, R27.1, U1.39 (GPIO27_ADC1), U5.1
/SFH_L: R8.2, U1.40 (GPIO28_ADC2), U6.1
/SOL1-: D3.2 (A), Q1.3 (D), sx1.SOL1-
/SOL1_MCU: R22.1, U1.12 (GPIO9)
/SOL2-: D4.2 (A), Q2.3 (D), sx1.SOL2-
/SOL2_MCU: R24.1, U1.28 (GPIO17)
/USB_D+: J2.2, R1.2
/USB_D-: J2.1, R2.2
/XIN: U1.20 (XIN), Y1.3
/XOUT: R35.1, Y1.1
/~USB_BOOT: J1.2, R3.1
GND: C1.2, C2.2, C3.2, C4.2, C5.2, C6.2, C7.2, C8.2, C9.2, C10.2, C11.2, C12.2, C13.2, C14.2, D2.2 (A), J1.1, J3.1, Q1.2 (S), Q2.2 (S), Q4.2 (E), R5.2, R10.2, R14.2, R16.2, R18.2, R20.2, R23.1, R25.1, R26.1, R28.2, R29.2, R33.1, U1.19 (TESTEN), U1.57 (GND), U2.1 (GND), U3.4 (GND), U4.2 (ADDR), U4.3 (GND), U5.2 (V-), U5.3 (+), U6.2 (V-), Y1.2, Z1.2, Z1.3, sx1.GND, sx1.S2-
unnamed: C15.1, D2.1 (K), R7.1, U5.4 (-)
unnamed: D5.2 (A), D6.2 (A), R34.1
unnamed: Q1.1 (G), R22.2, R23.2
unnamed: Q2.1 (G), R24.2, R25.2
unnamed: Q3.1 (G), Q4.3 (C), R32.2
unnamed: Q4.1 (B), R31.1
unnamed: R21.1, U1.7 (GPIO5)
unnamed: R2.1, U1.46 (USB_DM)
unnamed: R1.1, U1.47 (USB_DP)
unnamed: R35.2, U1.21 (XOUT)
unnamed: R27.2, R28.1, U6.3 (+)
unnamed: R8.1, R26.2, U6.4 (-)
VBUS: D1.2 (A), J3.2
VCC: C4.1, D1.1 (K), D3.1 (K), D4.1 (K), Q3.2 (S), R32.1, U2.2 (IN), sx1.S1C, sx1.SOL1+, sx1.SOL2+, sx1.VCC

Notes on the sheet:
Flash
Meter0
Power
Crystal
IF Sonar: high means button got pressed ELSE : low
Controller (RP2040 )
Meter1
SCL1
SDA1
USB

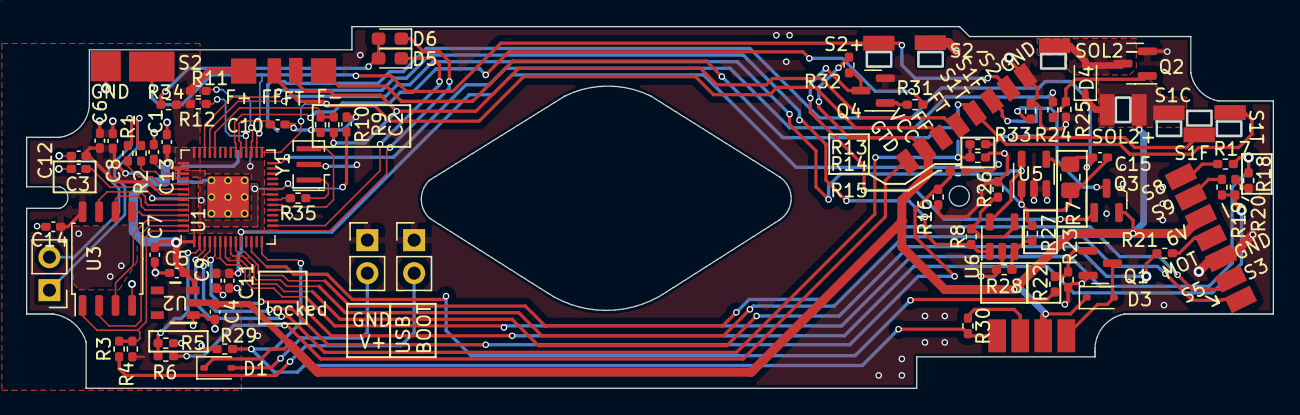
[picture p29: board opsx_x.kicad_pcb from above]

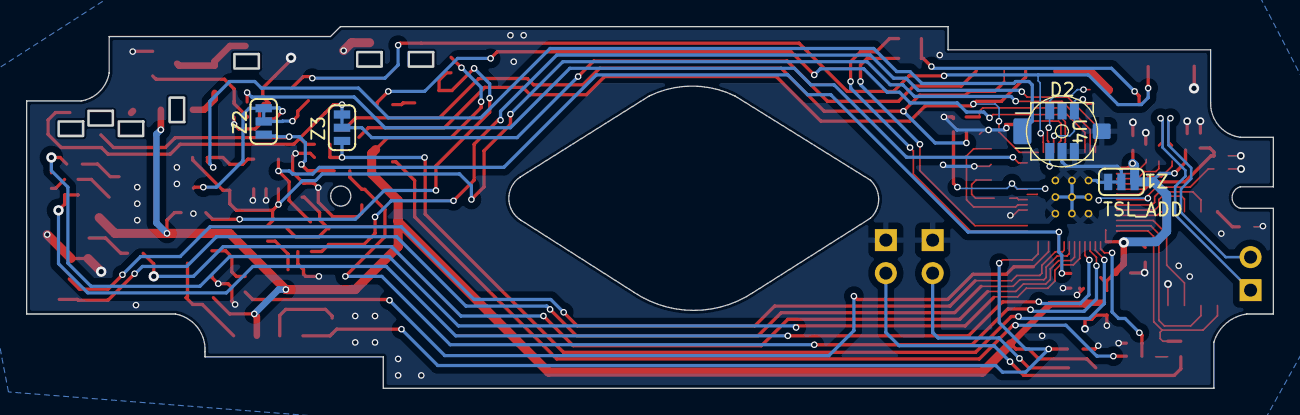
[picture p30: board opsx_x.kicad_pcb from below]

Board: 2 copper layers, 95.9 x 27.8 mm, 74 parts (5 on the bottom side), 59 nets.

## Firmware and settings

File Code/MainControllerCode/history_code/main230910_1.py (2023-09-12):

"""
Ver 1.0 20230912
正常调试版本，适合组装后使用
直接命名为main.py然后上传进板子的flash里就行
"""
from machine import Pin,PWM,ADC,I2C
import tsl2561,time,ssd1306,pcf8575

# Change Shutter_Delay_Back
# Change Motor Sequence S5


_CAMERA_DBG_ = True
_SAVE_FILE_ = True
Red_Button_Pressed = 1
if_focused = False
flash_connected = False
LM_ADDR = 41

de_bounce_time = 1
de_bounce_count = 10
adc_de_bonuce_count = 70

display_addr = 60
have_disp = False
encoder_addr = 32
have_enc = False
enc_pins = [4,5,6,7]
sec_enc_pins = [0,1,2,3]
# Code Start at "#End of Config"

# Config Output Pins <See Pins.xls>
shutter_pin = 9
apture_pin = 17
motor_pin = 5
LED_Y_PIN = 12
LED_B_PIN = 13
S1F_FBW_PIN = 22
FF_PIN = 11 # Flash Pin High to trigger
# End Config Output

# Config Input Pins <See Pins.xls>
S1F_PIN = 2 # Sw 1 Focus
S1T_PIN = 1 # Sw 1 Take Photo
S2_PIN = 14 # Flash Check Pin | SCL1
S3_PIN = 7
S5_PIN = 6
# End Config Input Pins

# Define Encoder Code
EC_ZERO = '1111'
EC_ONE = '0111'
EC_TWO = '1011'
EC_THREE = '0011'
EC_FOUR = '1101'
EC_FIVE = '0101'
EC_SIX = '1001'
EC_SEVEN = '0001'
EC_EIGHT = '1110'
EC_NINE = '0110'
EC_A = '1010'
EC_B = '0010'
EC_C = '1100'
EC_D = '0100'
EC_E = '1000'
EC_F = '0000'

SEC_EC_ZERO = '1111'
SEC_EC_ONE = '0111'
SEC_EC_TWO = '1011'
SEC_EC_THREE = '0011'
SEC_EC_FOUR = '1101'
SEC_EC_FIVE = '0101'
SEC_EC_SIX = '1001'
SEC_EC_SEVEN = '0001'
SEC_EC_EIGHT = '1110'
SEC_EC_NINE = '0110'

# Config ShutterDelay  sht(1/n) or sht(n)s
ev7 = 600
ev75 = 440
ev8 = 280
ev85 =210
ev9 = 155
ev95 =120
ev10 = 97
ev105 = 70
ev11 = 48
ev115 = 40
ev12 = 33
ev125 = 29
ev13 = 25
ev135 = 23
ev14 = 21
ev145 = 20
ev15 = 19
ev16 = 18

ShutterSpeedHuman = {ev7:'1/2', ev75:'1/3', ev8:'1/4', ev85:'1/6', ev9:'1/8', ev95:'1/10', ev10:'1/15', ev105:'1/20', ev11:'1/30', ev115:'1/45', ev12:'1/60',
                     ev125:'1/90', ev13:'1/125', ev135:'1/180', ev14:'1/250', ev145:'1/360', ev15:'1/500', ev16:'1/1000'}
# End Config ShutterDelay
#a=sht1000
#End of Config

def read_enc(enc_p=enc_pins):
    result = ""
    for i in enc_p:
        result += str(pcf.pin(i))
    #print(result,pcf.pin(1))
    return result

def plug_encoder():
    ec = read_enc(enc_pins)
    #ec = EC_ZERO #delete
    #print(ec)
    if ec == EC_ZERO:
        display.text('AUTO', 10, 2, 0)
        return 'A'
    elif ec == EC_ONE:
        display.text('B', 23, 2, 0)
        return 'B'
    elif ec == EC_TWO:
        # display.text('T', 23, 2, 0)
        return read_sec_plug_enc()
    
    elif ec == EC_THREE:
        display.text('1/2', 15, 2, 0)
        return ev7
    elif ec == EC_FOUR:
        display.text('1/4', 15, 2, 0)
        return ev8
    elif ec == EC_FIVE:
        display.text('1/6', 15, 2, 0)
        return ev85
    elif ec == EC_SIX:
        display.text('1/8', 15, 2, 0)
        return ev9
    elif ec == EC_SEVEN:
        display.text('1/10', 10, 2, 0)
        return ev95
    elif ec == EC_EIGHT:
        display.text('1/15', 10, 2, 0)
        return ev10
    elif ec == EC_NINE:
        display.text('1/20', 10, 2, 0)
        return ev105
    elif ec == EC_A:
        display.text('1/30', 10, 2, 0)
        return ev11
    elif ec == EC_B:
        display.text('1/60', 10, 2, 0)
        return ev12
    elif ec == EC_C:
        display.text('1/125', 5, 2, 0)
        return ev13
    elif ec == EC_D:
        display.text('1/250', 5, 2, 0)
        return ev14
    elif ec == EC_E:
        display.text('1/500', 5, 2, 0)
        return ev15
    elif ec == EC_F:
        display.text('1/1000', 1, 2, 0)
        return ev16

def read_sec_plug_enc():
    ec = read_enc(sec_enc_pins)
    # print('Sec Enc:', ec)
    one_sec = 1000
    one_min = one_sec*60
    if ec == SEC_EC_ZERO:
        display.text('T', 10, 2, 0)
        return 'T'
    elif ec == SEC_EC_ONE:
        display.text('T1S', 23, 2, 0)
        return 1*one_sec
    elif ec == SEC_EC_TWO:
        display.text('T2S', 23, 2, 0)
        return 2*one_sec
    elif ec == SEC_EC_THREE:
        display.text('T4S', 15, 2, 0)
        return 4*one_sec
    elif ec == SEC_EC_FOUR:
        display.text('T8S', 15, 2, 0)
        return 8*one_sec
    elif ec == SEC_EC_FIVE:
        display.text('T15S', 15, 2, 0)
        return 15*one_sec
    elif ec == SEC_EC_SIX:
        display.text('T30S', 15, 2, 0)
        return 30*one_sec
    elif ec == SEC_EC_SEVEN:
        display.text('T1M', 10, 2, 0)
        return 1*one_min
    elif ec == SEC_EC_EIGHT:
        display.text('T2M', 10, 2, 0)
        return 2*one_min
    elif ec == SEC_EC_NINE:
        display.text('T4M', 10, 2, 0)
        return 4*one_min

def showFrame():
    display.fill(0)
    display.fill_rect(0, 0, 128, 11, 1)
    display.vline(51, 0, 11, 0)
    display.vline(82, 0, 11, 0)
    
def meter():
    sensor.gain(16)
    try:
        lux = sensor.read()
    except ValueError:
        sensor.gain(1)
        lux = sensor.read()
    #print(lux,sensor.gain())
    if _CAMERA_DBG_:
        print("Raw Lux = {0:.2f} \t\tGain = {1:.2f} \t\t".format(lux, sensor.gain()))

    if _SAVE_FILE_:
        da_F = open('sht.txt','a')
        da_F.write("Raw Lux = {0:.2f} \tGain = {1:.2f} \n".format(lux, sensor.gain()))
        da_F.close()

    lux -= 0.4
    #* Magic Number
    lux *= 0.9
    if iso == '600':
        if 0.120<lux<=0.125: 
            return ev75,lux
        elif 0.125<lux<=0.1385:
            return ev8,lux
        elif 0.1385<lux<=0.152:
            return ev85,lux
        elif 0.152<lux<=0.185:
            return ev9,lux
        elif 0.185<lux<=0.22:
            return ev95,lux
        elif 0.22<lux<=0.275:
            return ev10,lux
        elif 0.28<lux<=0.345:
            return ev105,lux
        elif 0.345<lux<=0.468:
            return ev11,lux
        elif 0.468<lux<=0.58:
            return ev115,lux
        elif 0.58<lux<=0.802:
            return ev12,lux
        elif 0.802<lux<=1.115:
            return ev125,lux
        elif 1.115<lux<=1.6:
            return ev13,lux
        elif 1.6<lux<=2.35:
            return ev135,lux
        elif 2.35<lux<=3.4:
            return ev14,lux
        elif 3.4<lux<=4.2:
            return ev145,lux
        elif 4.2<lux<=10:#
            return ev15,lux
        elif 10<lux:#
            return ev16,lux
        else:
            return ev7,lux

# Inital camera
def camera_init():
    global sensor,plugI2c,plugscan,pcf,display,have_disp,have_enc,motor,shutter,apture,LED_Y,LED_B,FF,s2,s3,s5,s1t,s1f,S1F_FBW,ADC0,ADC1,iso
    lm_i2c = I2C(0,scl=Pin(21), sda=Pin(20), freq=400000)
    sensor = tsl2561.TSL2561(lm_i2c,41)
    plugI2c = I2C(1,scl=Pin(19), sda=Pin(18), freq=400000)
    
    plug_i2c_add = plugI2c.scan()
    plugscan = bool(plug_i2c_add) and len(plug_i2c_add)<=5
    print(plugI2c.scan())
    
        
    shutter = PWM(Pin(shutter_pin))
    shutter.freq(20000)
    shutter.duty_u16(0)
    apture = PWM(Pin(apture_pin))
    apture.freq(70000)
    apture.duty_u16(0)
    
    motor = Pin(motor_pin,Pin.OUT, value=0)
    LED_Y = Pin(LED_Y_PIN, Pin.OUT,value = 1)
    LED_B = Pin(LED_B_PIN, Pin.OUT,value = 1)
    FF = Pin(FF_PIN, Pin.OUT,value = 0)
    S1F_FBW = Pin(S1F_FBW_PIN, Pin.OUT,value = 0)
    
    s2 = Pin(S2_PIN,Pin.IN,Pin.PULL_UP)
    s3 = Pin(S3_PIN,Pin.IN,Pin.PULL_UP)
    s5 = Pin(S5_PIN,Pin.IN,Pin.PULL_UP)
    s1f = Pin(S1F_PIN,Pin.IN)
    s1t = Pin(S1T_PIN,Pin.IN)
    
    f = open('./dat/iso.txt')
    iso = f.readline()
    iso.replace(" ","")
    f.close()
    if _CAMERA_DBG_:
        print("ISO at %s!"%iso)
    if iso == '600':
        LED_Y.value(0)
        #display.text('600', 55, 2, 0)
    else:
        LED_B.value(0)
        #display.text('70', 60, 2, 0)
    
    if plugscan and encoder_addr in plug_i2c_add:
        pcf = pcf8575.PCF8575(plugI2c, encoder_addr)
        pcf.port = 0x0ff
        print("have plug")
        have_enc = True
        
    if plugscan and display_addr in plug_i2c_add:
        
        display = ssd1306.SSD1306_I2C(128, 32, plugI2c,addr=display_addr) # 设置宽度，高度和I2C通信
        have_disp = True
        display.contrast(1)
        print("have disp")
        showFrame()
        display.text('OFF', 94, 2, 0)
        if iso == '600':
            display.text('600', 55, 2, 0)
        else:
            display.text('70', 60, 2, 0)
        
        if have_enc:
            """
            enc = plug_encoder()
            if True or enc == 'A':
                shut_speed,raw = meter()                 
                display.text(str(ShutterSpeedHuman[shut_speed])+'s', 8, 23)
                if len(str(raw))>7:
                    raw = str(raw)[0:7]
                display.text(str(raw), 64, 23)
            elif enc == 'B':
                func = 'B'
            elif enc == 'T':
                func = 'T'
            """
            pass
        else:
            if not have_enc:
                display.text('Auto', 10, 2, 0)
            shut_speed,raw = meter()                 
            display.text(str(ShutterSpeedHuman[shut_speed])+'s', 8, 23)
            if len(str(raw))>7:
                raw = str(raw)[0:7]
            display.text(str(raw), 64, 23)
        display.show()
        

def close_led():
    LED_Y.value(1)
    LED_B.value(1)
    
def led_iso():
    if iso == '600':
        LED_Y.value(0)
    else:
        LED_B.value(0)

def de_bounce_read_pins(pin_list):
    global de_bounce_time,de_bounce_count
    pin_value = [0]*len(pin_list)
    for i in range(de_bounce_count):
        for j in range(len(pin_list)):
            pin_value[j] += pin_list[j].value()
        time.sleep_ms(de_bounce_time)
    for i in range(len(pin_value)):
        pin_value[i] = round(pin_value[i]/de_bounce_count)
        if i >1:
            i = 1
    return pin_value

def apture_engage():
    apture.duty_u16(65535)
    
def apture_disengage():
    apture.duty_u16(0)
        
        
def shut(Shutter_Delay, f="1"):
    
    #f = open('sht_cal.txt','a')
    #f.write("{0:.2f}\n".format(Shutter_Delay))
    #f.close()
    if _SAVE_FILE_:
        da_F = open('sht.txt','a')
        da_F.write("Mode: " + f)
        da_F.write(" Shutter Delay = {0:.2f}\n\n".format(Shutter_Delay))
        da_F.close()
    
    if _CAMERA_DBG_:
        print("Taking Picture")
        print("Shutter start to close!")
    # Shutter Close
    shutter.duty_u16(65535)
    time.sleep_ms(30)
    shutter.duty_u16(30000)
    if _CAMERA_DBG_:
        print("Shutter closed!")

    time.sleep_ms(30) # wait for shutter to fully close
    #time.sleep_ms(3000) #Delete

    # Motor starts moving
    motor.value(1)
    if _CAMERA_DBG_:
        print("Motor Start Moving")

    # Move until mirror reach correct position
    while True:
        if s3.value() == 1:
            motor.value(0)
            if _CAMERA_DBG_:
                print("Motor Stoped!")
            break
        
    if f=='0': #Engage apture 
        apture_engage()
        if _CAMERA_DBG_:
            print("apture_engage")
    
    time.sleep_ms(18) # Y delay
    
    shutter.duty_u16(0) #open shutter
    if _CAMERA_DBG_:
        print("Shutter Start to Open, Exposure Starts")

    # Start Exposure
    if f == '0': #Flash
        if _CAMERA_DBG_:
            print("Flash Mode!")
        gap = int(Shutter_Delay- 47)
        if gap < 0:
            gap = 0
        time.sleep_ms(47)
        FF.value(1)
        apture_disengage() # Apture goes back
        FF.value(0)
        time.sleep_ms(gap)
    
    elif f == '1': #Normal
        if _CAMERA_DBG_:
            print("Normal Mode!")
        start = time.ticks_us()
        if _CAMERA_DBG_:
            print("Start at", start)

        # utime.ticks_diff(old, new)
        deadline = time.ticks_add(start, Shutter_Delay*1000)
        while time.ticks_diff(deadline, time.ticks_us()) > 0:
            #print(time.ticks_diff(time.ticks_us(), start))
            continue
        """
        while time.ticks_ms() - start < Shutter_Delay:
            continue
        """
        # time.sleep_ms(Shutter_Delay)
        if _CAMERA_DBG_:
            print("End at", time.ticks_us(), "Dura us", time.ticks_us()-start)
    
    elif f == 'B': #B mode
        if _CAMERA_DBG_:
            print("B Mode!")
        time.sleep_ms(15)
        while True:
            dbpv = de_bounce_read_pins([s1f,s1t])
            foc = dbpv[0]
            tak = dbpv[1]
            time.sleep_ms(3)
            if tak != Red_Button_Pressed:
                break

    elif f == 'T': # T mode
        if _CAMERA_DBG_:
            print("T Mode!")
        
        # Wait until Button Released
        while True:
            dbpv = de_bounce_read_pins([s1f,s1t])
            foc = dbpv[0]
            tak = dbpv[1]
            if tak != Red_Button_Pressed:
                break
        # Wait until Button Pressed Again
        while True:
            dbpv = de_bounce_read_pins([s1f,s1t])
            foc = dbpv[0]
            tak = dbpv[1]
            time.sleep_ms(3)
            if tak == Red_Button_Pressed:
                break
    # End Exposure
    
    #time.sleep_ms(3000) #Delete

    # Close Shutter
    shutter.duty_u16(65535) # Close Shutter
    if _CAMERA_DBG_:
        print("Shutter Closing!")
    time.sleep_ms(30) # wait until shutter fully closed
    shutter.duty_u16(30000) # Keep Shutter Closed
    if _CAMERA_DBG_:
        print("Shutter Closd. Exposure Finished")
    time.sleep_ms(18)

    #start ejacting film
    motor.value(1)
    if _CAMERA_DBG_:
        print("Motor Working!")
    
    #time.sleep_ms(2000) #Delete

    # wait until film fully ejact
    while True:
        if s5.value() == 0:
        #if s5.value() == 1:#Delete
            motor.value(0)
            shutter.duty_u16(0)
            break


#Taking Photo, St = Shutter delay
def Take_Photo(St,Shut_Mode):
    #meter()
    LED_Y.value(1)
    LED_B.value(1)
    print("EXP Time:",str(St)," Flash:",str(Shut_Mode))
    
    """
    if not flash_connected:
        shut(St);
    else:
        shut(St,'0');
    """
    shut(St,Shut_Mode);
    print("Taken!")
    #led_iso()
    LED_Y.value(0)
    #return
#time.sleep_ms(1000)

def test_cam():
    time.sleep_ms(3800)
    LED_Y.value(1)
    shutter.duty_u16(65535)
    time.sleep_ms(3800)
    shutter.duty_u16(0)
    motor.value(1)
    LED_Y.value(0)
    
def Cam_Operation():
    global if_focused, CAMERA_DBG
    while True:
        # See if flash is connected
        flash_connected = not s2.value()
        #print(flash_connected, s2.value())
        # Get Redbutton Value
        dbpv = de_bounce_read_pins([s1f,s1t])
        foc = dbpv[0]
        tak = dbpv[1]
        if have_enc:      
            display.fill_rect(0, 0, 50, 11, 1)  
            enc = plug_encoder()
            display.show()
        # If button pressed half way and not focused
        if foc == Red_Button_Pressed and if_focused == False:
            S1F_FBW.value(1);  #delete
            if have_disp:
                showFrame()
                if iso == '600':
                    display.text('600', 55, 2, 0)
                else:
                    display.text('70', 60, 2, 0)
            
            # Meter Mode Select
            #Flash inserted
            if flash_connected: 
                shut_mode = '0'
                if (not have_enc) or enc =='A':
                    St = ev11
                    display.text(str(ShutterSpeedHuman[St])+'s', 8, 23)
                    _,raw = meter()
                    if len(str(raw))>7:
                        raw = str(raw)[0:7]
                    display.text(str(raw), 64, 23)
                    display.text(str(ShutterSpeedHuman[St])+'s', 8, 23)
                elif enc != 'B' and enc != 'T':
                    St = plug_encoder()
                    if St < ev11:
                        St = ev11
                    _,raw = meter()
                    if len(str(raw))>7:
                        raw = str(raw)[0:7]
                    display.text(str(raw), 64, 23)
                    display.text(str(ShutterSpeedHuman[St])+'s', 8, 23)
                else:
                    if have_disp:
                        display.text('---', 94, 2, 0)
                        display.fill_rect(0,12,128,52,0)
                        #display.text('Shutter open until button release', 8, 23)
                        display.text('Not Support', 8, 23)
                    continue

                if have_disp:
                    display.text('FLASH', 86, 2, 0)
                    display.text('1/30', 10, 2, 0)
            
            # No Flash
            else:
            # No Selector or Set to AUTO
                if (not have_enc) or enc == 'A': 
                    if not have_enc and have_disp:
                        display.text('Auto', 10, 2, 0)
                    if have_disp:
                        display.text('OFF', 94, 2, 0)
                    
                    #meter
                    if _SAVE_FILE_:
                        da_F = open('sht.txt','a')
                        da_F.write("Operation Mode = A\n")
                        da_F.close()

                    St,raw = meter()
                    
                    shut_mode = '1' # '0'-flash; '1'-normal; 'B'- B; 'T' - T
                    if have_disp:
                        if len(str(raw))>7:
                            raw = str(raw)[0:7]
                        display.text(str(raw), 64, 23)
                        display.text(str(ShutterSpeedHuman[St])+'s', 8, 23)
                    """
                    if St >= ev7:
                        LED_B.value(0)
                    else:
                        LED_B.value(1)
                    """
                
                # Select B Mode
                elif enc == 'B':
                    shut_mode = 'B'
                    if _SAVE_FILE_:
                        da_F = open('sht.txt','a')
                        da_F.write("Operation Mode = B\n")
                        da_F.close()
                    St = ev11
                    if not have_enc and have_disp:
                            #display.text('B', 10, 2, 0)
                            pass
                    if have_disp:
                        display.text('OFF', 94, 2, 0)
                        display.fill_rect(0,12,128,52,0)
                        #display.text('Shutter open until button release', 8, 23)
                        display.text('Open When Press', 8, 23)
                
                # Select T Mode
                elif enc == 'T' :
                    #sec_enc = read_sec_plug_enc()
                    if _SAVE_FILE_:
                        da_F = open('sht.txt','a')
                        da_F.write("Operation Mode = T\n")
                        da_F.close()
                    shut_mode = 'T'
                    St = ev11
                    if not have_enc and have_disp:
                            #display.text('B', 10, 2, 0)
                            pass
                    if have_disp:
                        display.text('OFF', 94, 2, 0)
                        display.fill_rect(0,12,128,52,0)
                        #display.text('Shutter open until button release', 8, 23)
                        display.text('Press to Stop', 8, 23)
                
                # Long exposure mode
                elif enc > ev7:
                    shut_mode = '1'
                    if _SAVE_FILE_:
                        da_F = open('sht.txt','a')
                        da_F.write("Operation Mode = T(select time)\n")
                        da_F.close()
                    St = enc
                    _,raw = meter()
                    if have_disp:
                        display.text('OFF', 94, 2, 0)
                        display.fill_rect(0,12,128,52,0)
                        if len(str(raw))>7:
                            raw = str(raw)[0:7]
                        display.text(str(raw), 64, 23)
                        display.text(str(St/1000)+'s', 8, 23)

                else:
                    St = plug_encoder()
                    if _SAVE_FILE_:
                        da_F = open('sht.txt','a')
                        da_F.write("Operation Mode = M\n")
                        da_F.close()
                    _,raw = meter()
                    shut_mode = '1' # '0'-flash; '1'-normal; 'B'; 'T'
                    if have_disp:
                        display.text('OFF', 94, 2, 0)
                        display.fill_rect(0,12,128,52,0)
                        if len(str(raw))>7:
                            raw = str(raw)[0:7]
                        display.text(str(raw), 64, 23)
                        display.text(str(ShutterSpeedHuman[St])+'s', 8, 23)

            if have_disp: 
                #display.text(str(ShutterSpeedHuman[St])+'s', 8, 23)
                display.show()
            if_focused = True
            print("Focusing!")
            if _CAMERA_DBG_:
                print(dbpv)
        
        if foc != Red_Button_Pressed and if_focused == True:
            S1F_FBW.value(0); #delete
            if_focused = False
            print("Stop Focus")
            if _CAMERA_DBG_:
                print(dbpv)

        # Button Fully Pressed -> Take Photo
        if tak == Red_Button_Pressed:
            Take_Photo(St, shut_mode) 
            #Take_Photo(ev7, shut_mode) #delete
            #Take_Photo(St, 'B') #delete
            #Take_Photo(St, 'T') #delete
            if _CAMERA_DBG_:
                print(dbpv)
    

if __name__ == "__main__":
    camera_init()
    #test_cam()
    #shut(1000)
    Cam_Operation()
    #apture_engage()
    #LED_Y.value(1)
    #LED_B.value(1)
    #shut(a)
    while True:
        #meter()
        #time.sleep_ms(1000)
        #test_cam1()
        #time.sleep_ms(2000)
        #shut(meter())
        break

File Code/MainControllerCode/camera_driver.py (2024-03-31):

"""
Ver 1.2.5 20240331 
by: Liu ZS
正常调试版本，适合组装后使用
上传进板子的flash内
"""

from machine import I2C, Pin, PWM, Timer
import tsl2561,time,ssd1306,pcf8575

# Define Encoder Code
EC_ZERO = '1111'
EC_ONE = '0111'
EC_TWO = '1011'
EC_THREE = '0011'
EC_FOUR = '1101'
EC_FIVE = '0101'
EC_SIX = '1001'
EC_SEVEN = '0001'
EC_EIGHT = '1110'
EC_NINE = '0110'
EC_A = '1010'
EC_B = '0010'
EC_C = '1100'
EC_D = '0100'
EC_E = '1000'
EC_F = '0000'

SEC_EC_ZERO = '1111'
SEC_EC_ONE = '0111'
SEC_EC_TWO = '1011'
SEC_EC_THREE = '0011'
SEC_EC_FOUR = '1101'
SEC_EC_FIVE = '0101'
SEC_EC_SIX = '1001'
SEC_EC_SEVEN = '0001'
SEC_EC_EIGHT = '1110'
SEC_EC_NINE = '0110'

#~ 快门速度定义位置
# 1.2.4
ev6 = 1050  # 1s
ev7 = 540	# 1/2
ev75 = 470	# 1/3
ev8 = 300	# 1/4
ev85 = 290	# 1/6
ev9 = 175	#* 1/8	OK
ev95 =136	# 1/10
ev10 = 97	#* 1/15	OK
ev105 = 79	# 1/20
ev11 = 60	#* 1/30 OK
ev115 = 52	# 1/45
ev12 = 45	#* 1/60 OK
ev125 = 41	# 1/90
ev13 = 37	#& 1/125
ev135 = 34	#& 1/180
ev14 = 32	# 1/250
ev145 = 28	#& 1/360    9   34
ev15 = 25	#& 1/500    4   15
ev16 = 23	#* 1/1000   OK
ev17 = 22	#& 1/2000

"""
# 1.2.3
ev6 = 1050  # 1s
ev7 = 540	# 1/2
ev75 = 470	# 1/3
ev8 = 300	# 1/4
ev85 = 290	# 1/6
ev9 = 175	#* 1/8	OK
ev95 =136	# 1/10
ev10 = 97	#* 1/15	OK
ev105 = 79	# 1/20
ev11 = 60	#* 1/30 OK
ev115 = 52	# 1/45
ev12 = 45	#* 1/60 OK
ev125 = 41	# 1/90
ev13 = 38	# 1/125
ev135 = 35	#& 1/180
ev14 = 32	#& 1/250    10  45
ev145 = 29	#& 1/360    9   34
ev15 = 26	#& 1/500    4   15
ev16 = 24	#& 1/1000    略亮
ev17 = 23	#& 1/2000    与1/1000相当
"""


"""
#! 1/1000s 快门慢了一档(照片太亮); 1/250 快门慢1/3以内
# 1.2.2
ev6 = 1050  # 1s
ev7 = 540	# 1/2
ev75 = 470	# 1/3
ev8 = 300	# 1/4
ev85 = 290	# 1/6
ev9 = 175	# 1/8	OK
ev95 =136	# 1/10
ev10 = 97	# 1/15	OK
ev105 = 79	# 1/20
ev11 = 60	# 1/30
ev115 = 52	# 1/45
ev12 = 45	# 1/60
ev125 = 41	# 1/90
ev13 = 38	# 1/125
ev135 = 36	# 1/180
ev14 = 34	# 1/250
ev145 = 32	# 1/360
ev15 = 29	# 1/500
ev16 = 26	# 1/1000
"""


ShutterSpeedHuman = {ev6:'1s', ev7:'1/2', ev75:'1/3', ev8:'1/4', ev85:'1/6', ev9:'1/8', ev95:'1/10',
                        ev10:'1/15', ev105:'1/20', ev11:'1/30', ev115:'1/45', ev12:'1/60',
                        ev125:'1/90', ev13:'1/125', ev135:'1/180', ev14:'1/250', ev145:'1/360',
                        ev15:'1/500', ev16:'1/1000', ev17:'1/2000'}

M_CMD_Dict = {ev6:'1s', ev7:'1/2', ev75:'1/3', ev8:'1/4', ev85:'1/6', ev9:'1/8', ev95:'1/10',
                ev10:'1/15', ev105:'1/20', ev11:'1/30', ev115:'1/45', ev12:'1/60',
                ev125:'1/90', ev13:'1/125', ev135:'1/180', ev14:'1/250', ev145:'1/360',
                ev15:'1/500', ev16:'1/1000', ev17:'1/2000'}

M_CMD_List = [i for i in M_CMD_Dict]
M_CMD_List.sort()

class Button3D():
    def  __init__(self) -> None:
        self.IF_DBG = True

        self.MAX_MENU = 3       # 初级菜单最大长度
        self.Menu = 0           # 在第几层菜单 0 - AUTO; 1 - T; 2 - B; 3 - M; 10 - 自拍计时
        self.Menu_0_9_mem = 0   # 存放从0-9离开时的菜单
        self.CAM_MODE = 'A'     # 相机工作模式
        self.M_Pos = 0          # 快门速度在列表中的索引值

        self.TimerSecList = [0, 3, 5, 10]      # 备选自拍定时器时间
        self.SelfTimerSecInd = 0

        if self.IF_DBG:
            print(self.CAM_MODE)
            print(M_CMD_List)

        self.old_button_value = '111'
        self.thereD_button_debounce_last = time.ticks_ms()
        self.thereD_button_debounce_time = 100

        self.push_down_start_time = time.ticks_ms()

    def if_can_update(self):
        # 如果时间不到防抖时间则直接返回
        if time.ticks_ms() - self.thereD_button_debounce_last < self.thereD_button_debounce_time:
            return 0
        return 1

    def update_Menu(self):
        if self.Menu == 0:
            if self.IF_DBG:
                print("进入A挡")
            self.CAM_MODE = 'A'

        elif self.Menu == 1:
            if self.IF_DBG:
                print("进入B挡")
            self.CAM_MODE = 'B'

        elif self.Menu == 2:
            if self.IF_DBG:
                print("进入T挡")
            self.CAM_MODE = 'T'

        elif self.Menu == 3:
            if self.IF_DBG:
                print("进入M挡")
            self.CAM_MODE = M_CMD_List[self.M_Pos]

    def down_button_call(self):
        if self.Menu == 1:
            if self.IF_DBG:
                print("在T门按下了下")

        if self.Menu == 3:
            if self.IF_DBG:
                print("在M挡按下了下")

            if self.M_Pos == 0:
                self.M_Pos = len(M_CMD_List) - 1
            else:
                self.M_Pos -= 1

    def up_button_call(self):
        if self.Menu == 1:
            if self.IF_DBG:
                print("在T门按下了上")

        if self.Menu == 3:
            if self.IF_DBG:
                print("在M挡按下了上")
            self.M_Pos = (self.M_Pos + 1) % (len(M_CMD_List))

        if self.Menu == 10:
            if self.IF_DBG:
                print("自拍定时时间增加")
            self.SelfTimerSecInd = (self.SelfTimerSecInd + 1) %(len(self.TimerSecList))


    def push_button_short_call(self):
        # 更高阶菜单时不响应
        if self.Menu > self.MAX_MENU:
            return

        if self.Menu <= self.MAX_MENU:
            self.Menu = (self.Menu + 1) % (self.MAX_MENU+1)

        self.update_Menu()

    def push_button_long_call(self):
        if self.Menu < 10:
            self.Menu_0_9_mem = self.Menu
            self.Menu = 10
        elif self.Menu == 10:
            self.Menu = self.Menu_0_9_mem
            self.update_Menu()
            print(self.Menu, "返回原本")

    def update(self, bt):
        change = 0

        #~ 向下按
        if self.old_button_value[0] == '1' and self.old_button_value[0] != bt[0]:
            if self.IF_DBG:
                print("按下了: 下")
            self.down_button_call()

        #~ 向上按
        if self.old_button_value[1] == '1' and self.old_button_value[1] != bt[1]:
            if self.IF_DBG:
                print("按下了: 上")
            self.up_button_call()

        #~ 向下按，在松开时动作（判断长短按）
        if self.old_button_value[2] == '1' and self.old_button_value[2] != bt[2]:
            if self.IF_DBG:
                print("按下了: 按下")
            self.push_down_start_time = time.ticks_ms()

        if self.old_button_value[2] == '0' and self.old_button_value[2] != bt[2]:
            if time.ticks_ms() - self.push_down_start_time > 1000:
                if self.IF_DBG:
                    print("长按")
                self.push_button_long_call()
            else:
                if self.IF_DBG:
                    print("短按")
                self.push_button_short_call()

        self.old_button_value = bt

        if self.Menu == 3:  # M 挡
            self.CAM_MODE = M_CMD_List[self.M_Pos]

        if self.Menu == 10:
            self.CAM_MODE = '---'

        return self.CAM_MODE, self.TimerSecList[self.SelfTimerSecInd]
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

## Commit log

2023-09-10 手动设置曝光时间从 1/1000 - 4分钟
2024-03-06 定时器高精度控制快门
2024-03-07 基本上可用
2024-03-07 新的手动控制方式
2024-03-08 可以正常工作（使用3维按钮）
2024-03-12 update to Kicad 8.0 & update BodyController to Rev 2.0
    [Controller_body.kicad_pcb, Controller_body.kicad_sch, bom.csv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]
2024-03-14 初步校准快门速度，现在呈现步进状态
2024-03-17 修复不闪光错误、完成空机测试，准备开始相纸测试
    [Controller_body.kicad_pcb]
2024-03-18 实验调整了快门速度
2024-03-18 修复若干BUG
2024-03-19 update camera_driver
2024-03-19 快门速度基本OK + 外壳基本OK
    [BodyControllerAsm.SLDASM, ControllerCase.SLDPRT, Controller_body.DXF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]
2024-03-31 自拍定时OK
    [ControllerCase.3mf, ControllerCase.SLDPRT, ControllerCase.STL]
2024-04-09 整理代码及Readme
    [Sx70PowerBack.kicad_pcb, Sx70PowerBack.kicad_sch]
2024-04-09 更新Readme
2024-09-09 重新整理仓库
    [BOM_right.xlsx, BodyControllerAsm.SLDASM, Case_Body_Control.STL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]
2024-09-09 外置电池设计
    [Sx70PowerBack.kicad_pcb, Sx70PowerBack.kicad_sch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]
2024-09-10 外置电池设计完毕，生成光绘文件
    [sx70battery-B_Cu.gbr, sx70battery-B_Mask.gbr, sx70battery-B_Paste.gbr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]
2024-09-11 电池2.1版本（CC识别可以充电）
    [102540Battery.SLDPRT, ASM.SLDASM, Case10mmBat.SLDPRT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]
